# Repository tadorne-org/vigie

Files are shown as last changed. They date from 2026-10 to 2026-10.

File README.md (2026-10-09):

# Vigie

**La vigie de la batterie.** Un nœud d'énergie toujours vivant pour petits
voiliers : une carte qui mesure l'énergie à bord, veille à quelques
microampères et rend compte depuis la cale — toute l'année, coupe-circuit
ouvert. Un projet [Tadorne](https://tadorne.org/).

## Le problème

Une batterie se vide pendant que le bateau est laissé seul. Les causes
habituelles — un instrument resté câblé en direct, un convertisseur qui ne
dort jamais, aucune recharge — sont invisibles depuis le quai.

## L'approche

- **Un seul nœud reste vivant.** Alimenté en amont du coupe-circuit, il mesure
  toute l'installation et rend compte ; tout le reste du bord peut être éteint
  ou en panne.
- **Un seul point de vérité.** Tout le courant passe par un shunt unique, lu
  en quatre fils dans le bus négatif. Aucun courant de charge ne traverse la
  carte.
- **Une veille qui ne vide pas.** Conversion choisie pour son courant de
  repos : ce qu'un convertisseur classique prendrait en un mois, Vigie le
  prend en un an.
- **Un réseau, pas un boîtier.** Vigie est la passerelle d'un petit réseau
  radio : afficheurs, centrale d'attitude, capteur de vent, second capteur de
  courant rejoignent au besoin, et chacun peut tomber sans emporter le reste.

## État

**Vigie 1.0** : carte conçue, assemblée, premiers tests concluants. Le projet
KiCad est publié sous CERN-OHL-S v2 ; le micrologiciel suivra, sous sa propre
licence. Huit jalons, du banc à une saison à flot :
[feuille de route](https://vigie.tadorne.org/fr/feuille-de-route/) ·
[documentation technique](https://vigie.tadorne.org/fr/documentation/) ·
[journal](https://vigie.tadorne.org/fr/journal/).

## Contenu du dépôt

| Dossier | Contenu | Licence |
|---|---|---|
| [`pcb/`](pcb/) | Projet KiCad de Vigie 1.0 : schéma, carte quatre couches, bibliothèque de symboles | [CERN-OHL-S v2](pcb/LICENSE) |
| [`site/`](site/) | Source Hugo de [vigie.tadorne.org](https://vigie.tadorne.org/) | contenu [CC BY-SA 4.0](site/LICENSE-CONTENT), gabarits [MIT](site/LICENSE) |

Le contenu de `pcb/` (tag `v1.0`) est identique à l'archive publiée, signée et
horodatée :
[`vigie-1.0-kicad.zip`](https://vigie.tadorne.org/files/vigie-1.0/vigie-1.0-kicad.zip),
[signature](https://vigie.tadorne.org/files/vigie-1.0/vigie-1.0-kicad.zip.asc),
[horodatage FreeTSA](https://vigie.tadorne.org/files/vigie-1.0/vigie-1.0-kicad.zip.tsr).

## Authenticité

Les commits et les fichiers publiés sont signés par la clé Tadorne
(`5420 08E3 53EC A628 B4D6  ACAD 8C03 243A FF69 5BF7`) ; chaque commit est
horodaté par FreeTSA (RFC 3161), jeton rangé dans les notes Git
`refs/notes/freetsa`. Vérification : <https://tadorne.org/verify/>.

```sh
git fetch origin refs/notes/freetsa:refs/notes/freetsa
git notes --ref freetsa show HEAD
```

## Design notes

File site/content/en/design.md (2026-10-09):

---
title: "The design"
translationKey: design
url: /design/
description: "Schematic, placement and routing, regenerated by versioned scripts."
---

Vigie is not drawn by hand. Its schematic, footprint placement and routing are produced by scripts kept with the design, so the same command rebuilds the same files.

- The schematic comes from a single description of the components and the nets.
- Board outline, mounting holes, footprint placement and the internal ground and 3.3 V planes are scripted.
- Signal routing is delegated to a router on the two outer layers only; the inner layers stay solid planes.
- Every build ends with a netlist check pin by pin, an electrical rule check and a design rule check.

{{< callout title="Board" >}}
86 × 54 mm, four layers, sixty-nine footprints, fifty-four nets. Measurement across an external 100 A shunt, four-wire.
{{< /callout >}}

The KiCad project is published under [CERN-OHL-S v2](/files/vigie-1.0/LICENSE-CERN-OHL-S-2.0.txt): [archive](/files/vigie-1.0/vigie-1.0-kicad.zip), its [signature](/files/vigie-1.0/vigie-1.0-kicad.zip.asc) and [FreeTSA timestamp](/files/vigie-1.0/vigie-1.0-kicad.zip.tsr). The bill of materials exports from the schematic; the calibration procedure will follow with the firmware.

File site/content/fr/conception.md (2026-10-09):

---
title: "La conception"
translationKey: design
url: /fr/conception/
description: "Schéma, implantation et routage, régénérés par des scripts versionnés."
---

Vigie n'est pas dessinée à la main. Son schéma, l'implantation des empreintes et le routage sont produits par des scripts conservés avec la conception : la même commande reconstruit les mêmes fichiers.

- Le schéma provient d'une description unique des composants et des nets.
- Contour de carte, trous de fixation, implantation des empreintes et plans internes de masse et de 3,3 V sont scriptés.
- Le routage des signaux est confié à un routeur, sur les deux couches externes seulement ; les couches internes restent des plans pleins.
- Chaque build se termine par un contrôle de la netlist broche par broche, un contrôle des règles électriques et un contrôle des règles de dessin.

{{< callout title="Carte" >}}
86 × 54 mm, quatre couches, soixante-neuf empreintes, cinquante-quatre nets. Mesure aux bornes d'un shunt externe de 100 A, en quatre fils.
{{< /callout >}}

Le projet KiCad est publié sous [CERN-OHL-S v2](/files/vigie-1.0/LICENSE-CERN-OHL-S-2.0.txt) : [archive](/files/vigie-1.0/vigie-1.0-kicad.zip), sa [signature](/files/vigie-1.0/vigie-1.0-kicad.zip.asc) et son [horodatage FreeTSA](/files/vigie-1.0/vigie-1.0-kicad.zip.tsr). La nomenclature s'exporte du schéma ; la procédure d'étalonnage suivra avec le micrologiciel.

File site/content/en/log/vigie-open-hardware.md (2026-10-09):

---
title: "Vigie goes open hardware"
translationKey: log/vigie-open-hardware
date: 2026-09-28
description: "Vigie 1.0's schematic and four-layer board are published under CERN-OHL-S v2."
params:
  tags: ["vigie", "hardware", "licence"]
---

Vigie 1.0's KiCad project is published under the **CERN-OHL-S v2** hardware
licence. Schematic, four-layer board and symbol library: the minimum needed to
open, study and rebuild the board is downloadable now.

## What is published

| Item | Format |
|---|---|
| Schematic | KiCad |
| Printed circuit board | KiCad, four layers, routed |
| Library | the project's `CH340C_3V3` symbol |

The project opens as-is in KiCad 10. The bill of materials is not supplied
separately: it exports straight from the schematic, with KiCad's own tools.

## Responsibility and limits

- **The board is untested.** Integration testing is under way, and the real
  quiescent current is not measured yet. The design is published as it stands,
  open points included — antenna in a closed locker, shunt orientation to be
  confirmed.
- **No warranty.** The licence text is explicit: the source is provided as-is.
  A board switching 12 V aboard involves the safety of whoever wires it.
- **Firmware is still to be published.** This archive covers the hardware; the
  code that reads the INA226 and keeps watch through the winter will follow
  under its own licence.

## Where

- [KiCad project (ZIP)](/files/vigie-1.0/vigie-1.0-kicad.zip)
- [Detached signature (`.asc`)](/files/vigie-1.0/vigie-1.0-kicad.zip.asc)
- [FreeTSA timestamp (`.tsr`)](/files/vigie-1.0/vigie-1.0-kicad.zip.tsr)
- [CERN-OHL-S v2 licence text](/files/vigie-1.0/LICENSE-CERN-OHL-S-2.0.txt)

The archive is signed with the Tadorne publication key; the fingerprint is in
the page footer. It is also timestamped by FreeTSA (RFC 3161).

The published source is authoritative; it is also described on [the Design
page](/design/), which recalls how the board is produced.

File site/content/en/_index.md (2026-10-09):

---
title: "Vigie"
translationKey: home
description: "An always-on energy node for small boats: one board that measures the battery, watches through the winter and reports from the bilge. A Tadorne project."
params:
  hero:
    eyebrow: "A Tadorne project"
    lead: "The battery's lookout. One board that measures the energy aboard, keeps watch on a few microamps and reports from the bilge — all year, main switch off."
    ctas:
      - label: "The project"
        url: "/project/"
      - label: "The design"
        url: "/design/"
      - label: "Kit — coming soon"
        url: "/interest/"
        solid: true
  video:
    mp4: "/video/vigie-en.mp4"
    webm: "/video/vigie-en.webm"
    poster: "/video/vigie-en-poster.jpg"
    caption: "Vigie 1.0: the exploded stack, then the board aboard — shunt, Kelvin pair, Bluetooth LE."
  figures:
    - label: "Board"
      value: "86 × 54 mm"
    - label: "Layers"
      value: "4"
    - label: "Watch current"
      value: "22 µA"
    - label: "Measured current"
      value: "100 A"
    - label: "Regime"
      value: "All year"
  notes:
    - title: "One point of truth"
      body: "All current passes the shunt; the board only reads it. No second path, no silent error."
    - title: "Always alive"
      body: "Fed upstream of the main switch, it is the one module that outlives the winter."
    - title: "Built from scripts"
      body: "Schematic, placement and routing are regenerated by versioned code, not drawn by hand."
  closing:
    title: "Join Vigie"
    body: "Beta testers and contributors wanted. The board is on the bench, the season afloat comes next."
    url: "mailto:contact@tadorne.org?subject=Vigie%20%E2%80%94%20beta%20testing%20%2F%20contribution&body=Hello%2C%0A%0AI%20would%20like%20to%20get%20involved%20in%20Vigie.%0A%0AWhat%20I%20can%20bring%3A%0A-%0A%0AWhat%20I%20am%20looking%20for%3A%0A-%0A%0AThanks."
    label: "Write to us"
---

Battery state read at the shunt, and a watch kept all year.

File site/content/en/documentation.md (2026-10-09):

---
title: "Technical documentation"
translationKey: documentation
url: /documentation/
description: "Architecture, board, measurement, firmware and network of Vigie 1.0 — work in progress."
params:
  eyebrow: "Vigie 1.0"
---

{{< callout title="Work in progress" >}}
This page is the documentation of **Vigie 1.0**, still being written.

**[See the log](/log/)** for the latest state.
{{< /callout >}}

Vigie is a single board that measures the energy of a sailboat or a 12 V battery
pack, keeps watch all year and reports. It replaces the "ESP32 devkit + INA226
module + LM2596 converter" stack with an 86 × 54 mm four-layer board, and sits
**upstream of the main switch** — the one module that stays alive through the
winter: its converters draw 22 µA per stage, and the whole board stays below a
milliamp.

<figure class="doc">
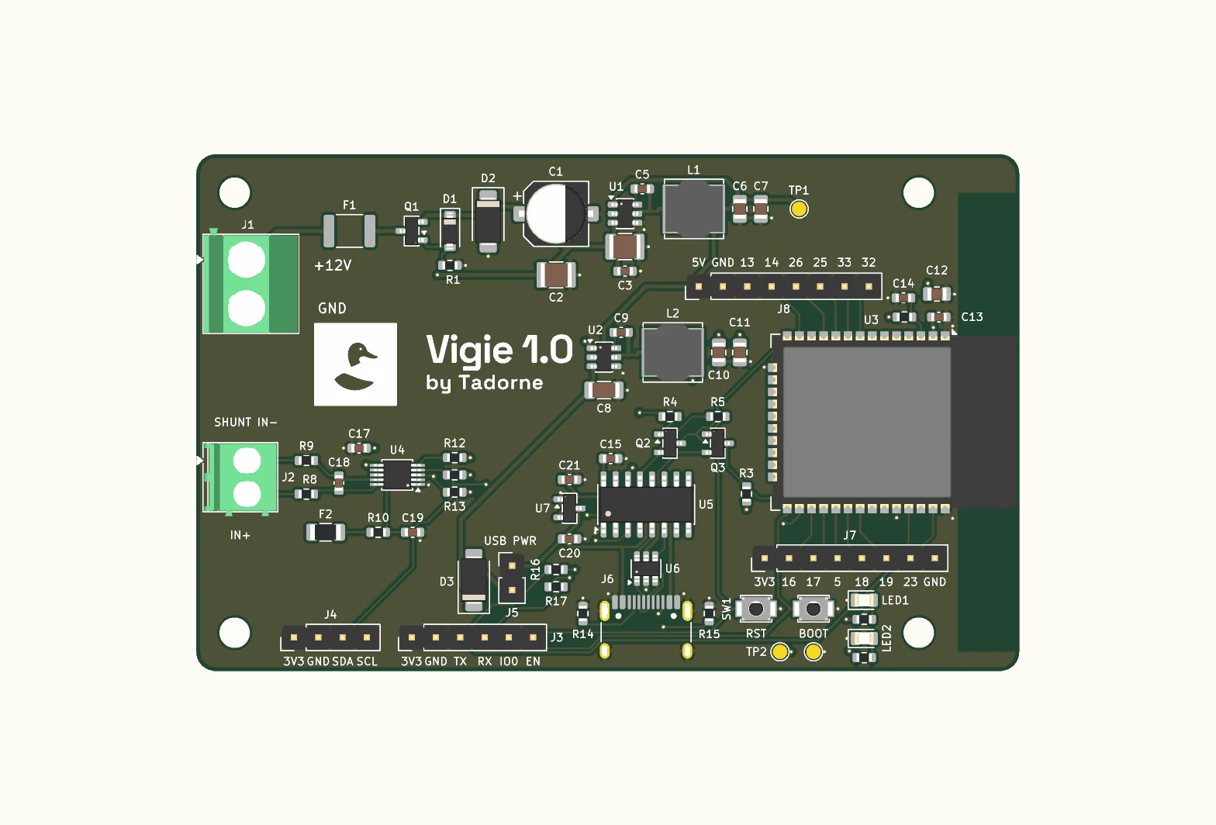
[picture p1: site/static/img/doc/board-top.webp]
Render of the Vigie 1.0 board, component side.
  
  <figcaption><b>Vigie 1.0</b>, component side: 12 V and shunt terminals on the left, ESP32-WROOM-32E on the right, converters in the middle, "Vigie 1.0 — by Tadorne" in the silkscreen.</figcaption>
</figure>

## Overview

One point of truth: all current aboard flows through a **100 A / 75 mV shunt**
in the negative bus, and the board only reads the voltage across it, in four
wires. No load current flows through the board.

<figure class="doc">
  Block diagram of Vigie 1.0: power, measurement, programming and expansion around the ESP32.
  <figcaption>Block diagram: 12 V → 5 V → 3.3 V power chain, Kelvin-wired INA226 measurement, USB-C programming and expansion headers, around the ESP32-WROOM-32E.</figcaption>
</figure>

| Characteristic | Value |
|---|---|
| Dimensions | 86 × 54 mm, R2 corners, four M3 holes |
| Layers | 4: signal / ground plane / +3.3 V plane / signal |
| Microcontroller | ESP32-WROOM-32E, PCB antenna on the right flank, copper-free zone on all four layers |
| Measurement | INA226AIDGSR, external 100 A / 75 mV shunt, four-wire Kelvin connection |
| Power | 12 V → 5 V → 3.3 V, 2 A per stage, 22 µA quiescent current per stage |
| Protection | polyfuse, reverse-polarity P-MOSFET, SMAJ16A TVS, 100 mA fuse on VBUS |
| Programming | CH340C + USB-C, automatic DTR/RTS reset |
| Expansion | two 1×8 headers: 12 GPIO, +3.3 V, +5 V, I2C, UART, reserved RS485 |
| Footprints | 69 footprints and 4 holes, 54 nets |

## The board

### Power

Two switching converters from the same family share the chain: **AP63205WU** for
12 V → 5 V and **AP63203WU** for 5 V → 3.3 V, 2 A each at 1.1 MHz. The hard
point of an always-on node is their quiescent current: **22 µA per stage**, where
an LM2596 draws 5 to 10 mA continuously, about 3.5 Ah a month taken for nothing.

The input is protected by a polyfuse, a reverse-polarity P-MOSFET (45 mΩ, with
its gate zener — mandatory, since the battery reaches 14.4 V while charging) and
an SMAJ16A TVS. On the bench, jumper **J5** powers the board from USB; it is open
by default so the 5 V cannot climb back to the battery terminal. The **CH340C**
is powered by an LDO taken from USB VBUS alone: unplugged, it draws nothing.

### Measurement

The INA226 works across a **0.75 mΩ** shunt in the negative bus: 75 mV of common
mode instead of 12 V, and `VBUS` reads the battery voltage directly. Its range is
fixed at **±81.92 mV** — the `ADCRANGE` bit does not exist on this part, unlike
the INA228 — which gives, with the native 2.5 µV step, a resolution of
**3.33 mA**. One hundred amps use 91.6 % of full scale.

Gain, zero and current sign are set in software (`i_gain`, `i_offset_mA`,
`i_invert`): a J2 wired the wrong way round is corrected without taking the
board apart. Amp-hour counting is software too, since the INA226 has no charge
accumulator. Finally, `ALERT` arrives on **GPIO 4**, an RTC pin: it can wake the
ESP32 from deep sleep.

<figure class="doc">
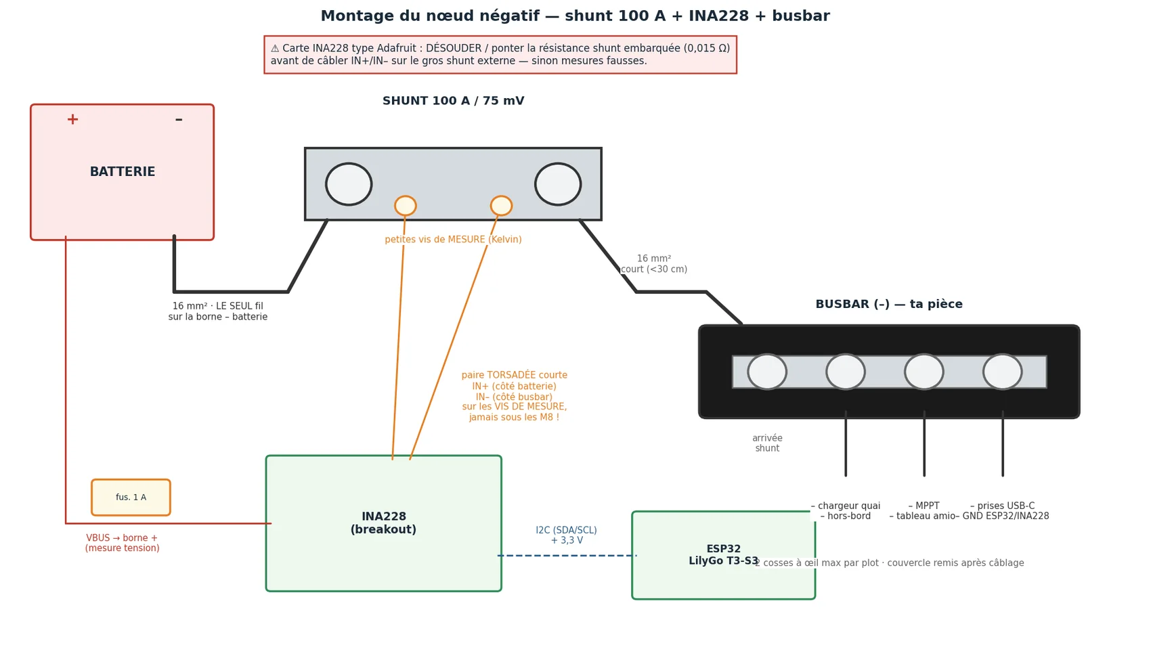
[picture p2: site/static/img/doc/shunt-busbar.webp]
Mounting the node on the negative bus: shunt, Kelvin pair and busbar.
  
  <figcaption>The negative-bus mounting, study figure: the Kelvin pair is taken
  from the shunt's <b>small measurement screws</b>, never from under the power
  bolts, and the board's return joins the negative bus as close to the shunt as
  possible. The principle is Vigie 1.0's own, which carries no load
  current.</figcaption>
</figure>

The precaution is not theoretical: at 100 A, 20 cm of 16 mm² cable is already
23 mV, close to a third of the measurement range.

### Routing and placement

The two inner layers are **solid planes with no tracks at all**: In1 for ground,
In2 for +3.3 V. Every SMD ground and +3.3 V pad drops to its plane through its
own via, placed and locked before routing. Signal routing fits on the two outer
layers.

<figure class="doc">
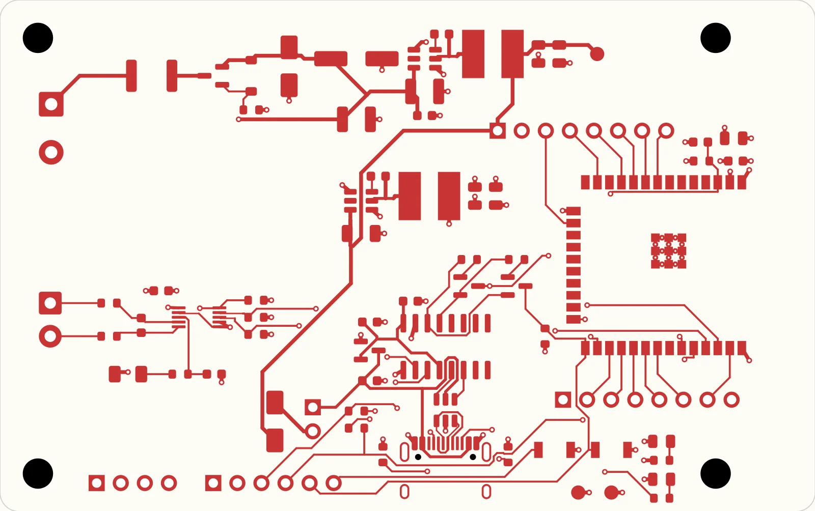
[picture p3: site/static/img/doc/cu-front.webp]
Front copper routing of Vigie 1.0.
  
  <figcaption>Front copper routing (F.Cu): signals fit on the two outer layers,
  the two inner layers staying solid planes.</figcaption>
</figure>

<figure class="doc">
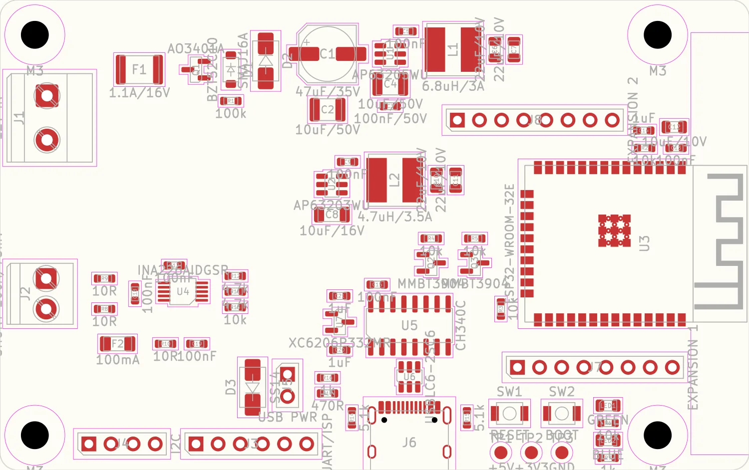
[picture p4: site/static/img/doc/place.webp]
Placement and silkscreen of Vigie 1.0.
  
  <figcaption>Placement and silkscreen: every reference is placed where it covers
  neither a pad nor a via.</figcaption>
</figure>

### Connectors

| Ref. | Role | Pinout |
|---|---|---|
| J1 | 12 V input (5.08 mm terminal block) | 1 = +12 V battery (external 2 A fuse) · 2 = GND, load side of the negative bus |
| J2 | Shunt (3.5 mm terminal block) | 1 = IN− · 2 = IN+ — sign to be confirmed at bring-up |
| J3 | UART / ISP | 3V3 · GND · TX · RX · IO0 · EN |
| J4 | I2C | 3V3 · GND · SDA · SCL |
| J5 | USB PWR jumper | close to power from USB, without the battery only |
| J6 | USB-C | programming |
| J7 | Expansion 1 | 3V3 · IO16 · IO17 · IO5 · IO18 · IO19 · IO23 · GND |
| J8 | Expansion 2 | 5V · GND · IO13 · IO14 · IO26 · IO25 · IO33 · IO32 |

I2C is on SDA 21 / SCL 22, the status LED on GPIO 2, the BOOT button on GPIO 0,
the console on TX 1 / RX 3. GPIO 16, 17 and 18 are grouped on J7 for the MPPT's
future RS485. The strapping pins 12 and 15, like GPIO 34 to 39, are not brought
out.

## Firmware

The firmware runs on PlatformIO, with a pinned pioarduino platform
(Arduino-ESP32 3.3.11 / ESP-IDF 5.5) and no external library. It already runs on
a bare ESP32 devkit: a battery simulator stands in for the missing INA226, and
every simulated measurement carries the `SIM` flag all the way into the log and
onto the air.

The cycle is deep sleep broken by short wake-ups:

| Task | Default period | Cost |
|---|---|---|
| Measurement | 5 min | 110 ms awake |
| Recording | 5 min | average, minimum and maximum of the period |
| Brief BLE advertisement | at every measurement | about 0.4 s awake, estimated |
| Radio push | 15 min | 1.8 s awake, of which 1.1 s of BLE advertising |
| Wintering | push every 6 h | survival mode |

Measurement averages 1024 INA226 conversions, a **9.6 s** sliding window that
keeps averaging while the ESP32 sleeps. State of charge is coulometric counting:
trapezoids between measurements, 0.90 charge efficiency, Peukert exponent 1.25
in discharge beyond C/20. It resynchronises to 100 % when the voltage holds
above the threshold with a low tail current, and re-anchors on the open-circuit
voltage table after four hours at rest.

The log lives in a raw 896 KB partition, with no file system: 32-byte records
protected by a CRC. At the default cadence the ring keeps about **95 days** of
samples and **2.5 years** of daily summaries. The board has no backed-up clock:
time arrives from the admin page, from the gateway or from the console, and a
`time_sync` record makes it possible to date what came before.

Battery protection is a staircase, and a degradation needs two consecutive
evaluations — an engine start does not cut the node:

| Voltage | State | Effect |
|---|---|---|
| 12.2 V and above | nominal | |
| below 12.2 V | throttled | push halved |
| below 11.9 V | survival | push every 6 h, no catch-up |
| below 11.5 V | cutoff | final alert, then radio silence; the INA226 wakes the node once the voltage is back above 12.6 V |

Administration is an access point, `Vigie-XXXX` (WPA2, captive portal), opened
on cold start or by holding BOOT: dashboard, 6 h to 30 day history with CSV
exports, settings, SOC reset, OTA update and log erase. The serial console
offers the same functions.

<figure class="doc">
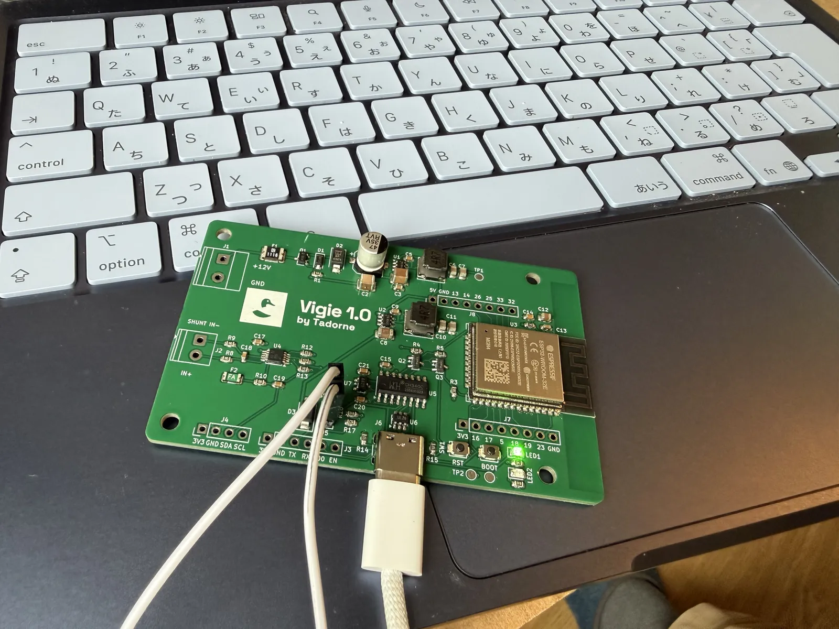
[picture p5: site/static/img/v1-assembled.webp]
Assembled Vigie 1.0 board, powered over USB-C, on the bench.
  
  <figcaption>The first assembled board: 3.3 V present, CH340C recognised, firmware running, INA226 answering on I2C.</figcaption>
</figure>

<figure class="doc">
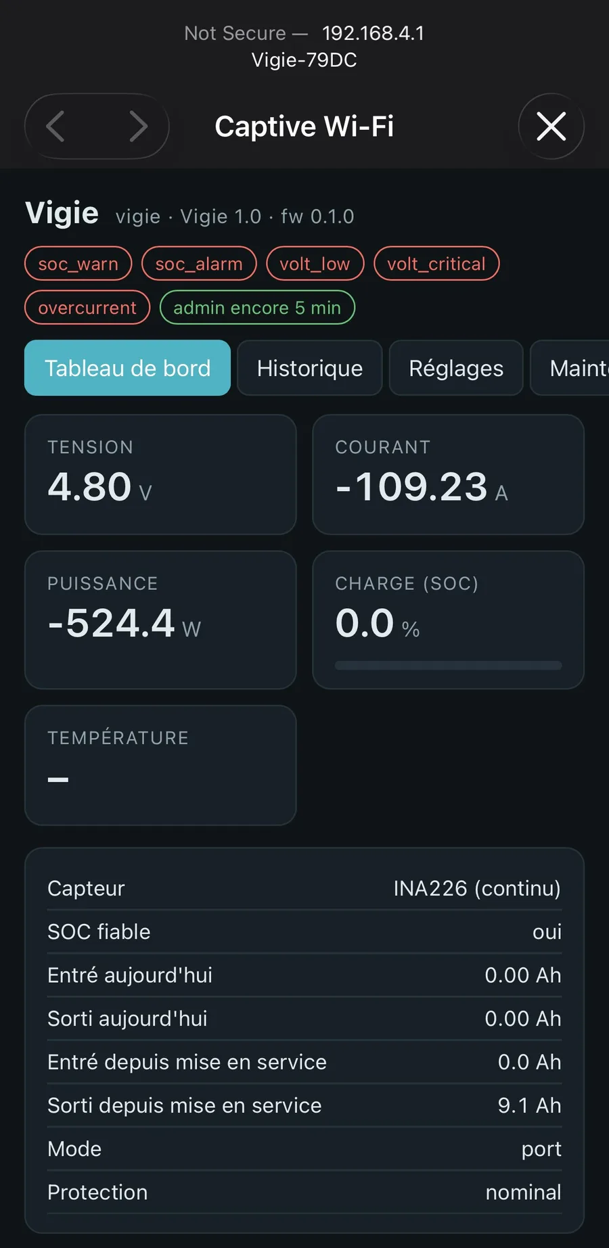
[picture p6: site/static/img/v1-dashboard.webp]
Vigie 1.0 dashboard, served from the board's own access point.
  
  <figcaption>The admin page, served from the board's own access point. With no shunt, the current columns still show the INA226's full scale.</figcaption>
</figure>

## Network and application

The node pushes its measurements in two complementary ways. On the local
network, **TsubameBus**: encrypted ESP-NOW frames, a 12-byte header and a CBOR
body, with `HELLO`, `ENERGY`, `ALERT` and `LOG_BATCH`. A receiver acknowledges
the last record it got, so a module absent for a week recovers the whole week
when it returns. Towards phones, a **[BTHome v2](https://bthome.io)**
advertisement over Bluetooth LE, readable as-is by Home Assistant or nRF
Connect, with optional AES-CCM encryption.

A [Signal K](https://signalk.org/) implementation is planned.

| What Vigie broadcasts | Received by an iPhone | Content |
|---|---|---|
| BLE BTHome v2 advertisement | yes | state of charge, voltage, current, power, temperature |
| Scan response (manufacturer block) | yes | Bluetooth MAC, status flags, active alerts |
| ESP-NOW frames | no | iOS gives no access to raw Wi-Fi frames |

The **Tadorne** iPhone app listens passively: no connection, no pairing, nothing
is transmitted. It keeps the history of what it caught, with the app open; the
full log stays in the node's flash.

<div class="photo-grid">
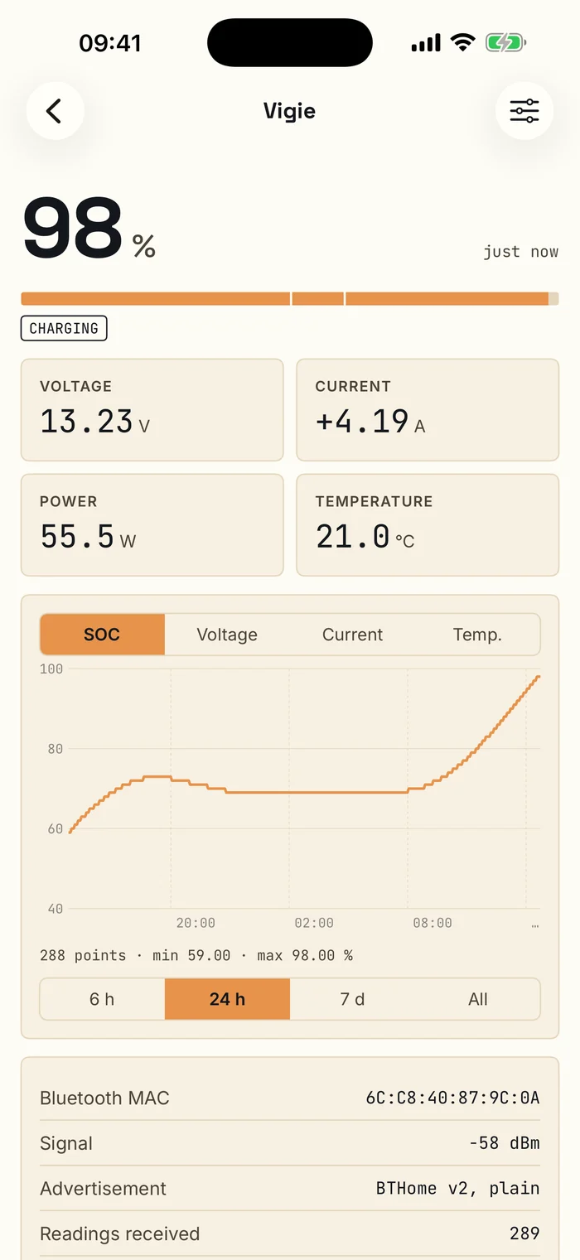
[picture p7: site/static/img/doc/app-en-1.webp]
Node detail screen in the Tadorne app: state of charge, measurements and chart.
  
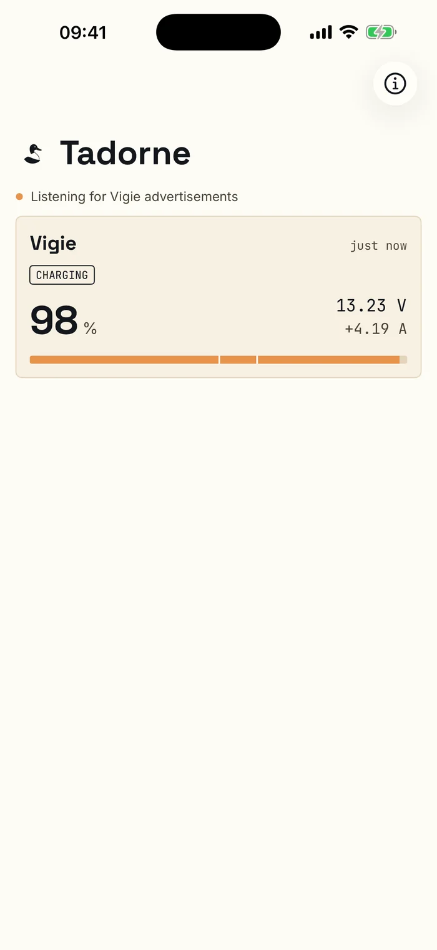
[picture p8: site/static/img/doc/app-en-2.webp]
Node list in the Tadorne app.
  
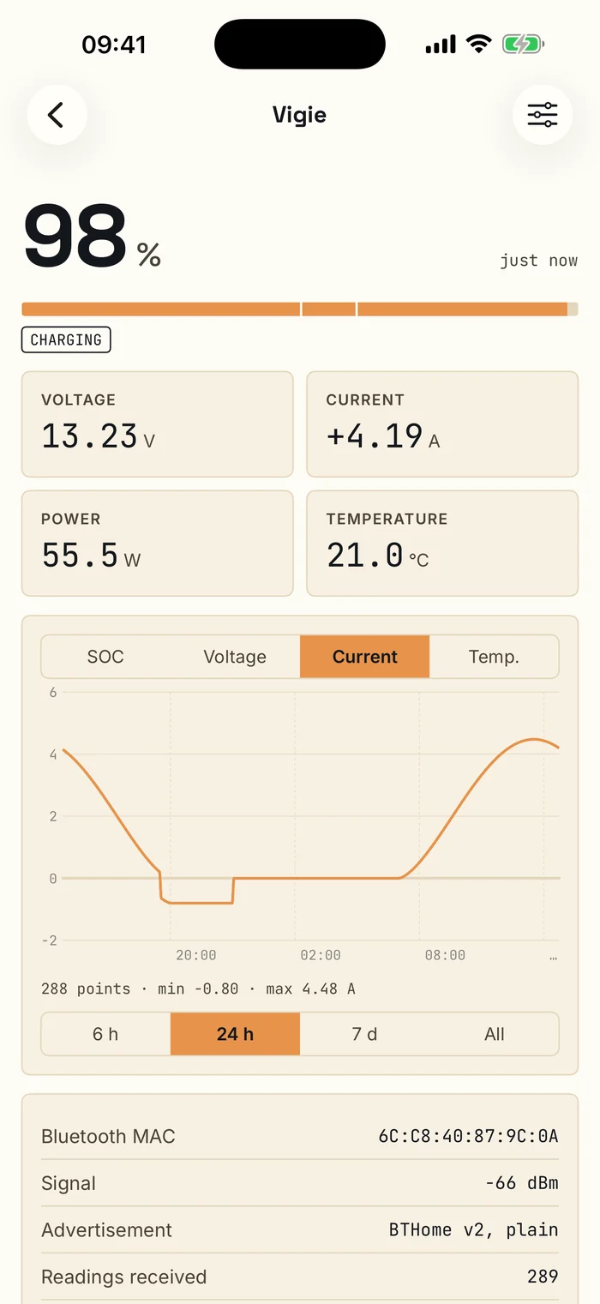
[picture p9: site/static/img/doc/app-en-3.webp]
Current history in the Tadorne app.
  
</div>

<p class="meta">Tadorne app — node detail, node list, current history.</p>

This revision of the board carries **neither LoRa nor LTE**: it is the
measurement post, not the Internet gateway. The radio arbitration remains open,
and the gateway will join the network without modifying the board.

## State and open points

| Point | State |
|---|---|
| Real quiescent current | to be measured at bring-up — it is what sets the winter autonomy |
| Current sign at the shunt | to be confirmed at first wiring |
| Antenna in a closed locker, in the bilge | open point; the ESP32-WROOM-32UE variant, with a u.FL remote antenna, fits the same footprint |
| RS485 for the EPEver MPPT | not fitted; external MAX3485 module on J7 |
| Firmware | still to be published |
| Bill of materials and calibration procedure | to come with the firmware |

The bench validated the build of all three environments, the sleep cycle, the
log and its recovery after reset, the 100 % resynchronisation and the low-voltage
cutoff. Real ESP-NOW frame reception, BLE reception and everything touching the
real INA226 remain to be verified on the board.

## Source: the log

Every note in the log is a source for this page, and the log is authoritative.

{{< log-sources >}}

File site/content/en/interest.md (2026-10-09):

---
title: "Registering interest"
translationKey: interest
url: /interest/
eyebrow: "Vigie 1.0 — pre-series"
description: "Neither a sale nor a pre-order: a list of interested people, to decide whether a small batch makes sense."
figures:
  - label: "Board"
    value: "86 × 54 mm"
  - label: "Measurement"
    value: "INA226 · 100 A shunt"
  - label: "Sleep current"
    value: "22 µA"
  - label: "Status"
    value: "On the bench"
---

**Vigie** is the energy node board: an ESP32 and an INA226 that measure a small sailboat's battery, upstream of the main switch, down to a few microamps — enough to last a whole winter layup without draining the battery.

Vigie 1.0 is arriving on the bench. A few boards will be assembled beyond what the boat needs. Before turning it into a product — and before taking on the conformity work that selling imposes — one question remains: **does this object interest anyone other than its author?**

This page exists to answer that. It sells nothing.

{{< callout title="What this page is not" >}}
- It is **not a pre-order**: no payment, no commitment, no promised date.
- It is **not a reservation**: the number of boards available is not known yet.
- It is **not a form**: the message is sent from the visitor's own mail client. No script, no cookie, no data passed to a third party — as everywhere on this site.
{{< /callout >}}

## Answering

The link below opens a pre-filled message. Six lines are enough. The message goes straight from your mail client to `contact@tadorne.org`; nothing passes through the site.

<p style="margin-top:1.5rem"><a class="btn btn--solid" href="mailto:contact@tadorne.org?subject=Vigie%201.0%3A%20registering%20interest&amp;body=Boat%20%28model%2C%20length%29%3A%0D%0AHome%20port%20and%20sailing%20area%3A%0D%0ACurrent%20installation%20%28battery%2C%20charging%2C%20shunt%20if%20any%29%3A%0D%0AWhat%20would%20interest%20you%20%28board%20only%20%2F%20kit%3A%20board%20%2B%20shunt%20%2B%20spacers%20%2F%20follow%20the%20project%29%3A%0D%0AWintering%20aboard%3A%20yes%20%2F%20no%0D%0APreferred%20documentation%20language%3A%20English%20%2F%20French">Write to Tadorne</a></p>

If the link does not open, write to `contact@tadorne.org` with these six lines:

1. Boat — model, length
2. Home port and sailing area
3. Current installation — battery, charge, shunt if any
4. What would interest you — board only, kit (board + shunt + spacers), or simply following the project
5. Wintering aboard — yes or no
6. Preferred documentation language — English or French

## What happens next

Every message gets an answer. People on this list are told first if a small batch goes ahead, and before any public announcement.

Replies are used only to decide what the project does next. They are neither sold nor shared, and a single message is enough to have them deleted.

Progress is kept up to date in [the roadmap](/roadmap/) and [the log](/log/).

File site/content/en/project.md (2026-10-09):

---
title: "The project"
translationKey: project
url: /project/
description: "One board that measures the boat's energy, all year round."
params:
  eyebrow: "Vigie"
---

## The problem

A battery goes flat while the boat is left alone. The usual causes — an instrument still wired live, a converter that never sleeps, no recharge at all — are invisible from the quay.

## The approach

One node, fed upstream of the main switch, is the only thing that stays alive: it measures the whole installation and reports. Everything else on board may be switched off or broken; the watch goes on.

## One point of truth

All current passes through a single shunt, in the negative bus. The board reads the voltage across it in four wires — two for the load, two for the measure. No charge flows through the board itself, so nothing sits in parallel to falsify the count.

## The quiet drain

A watch is only useful if it does not itself empty the battery. Conversion is chosen for its quiescent current, counted in microamps rather than milliamps: what a conventional converter would take in a month, Vigie takes in a year.

## A network, not a box

Vigie is the always-on gateway of a small radio network. Displays, an attitude sensor, a wind sensor, a second current sensor: each joins when needed, and each may fail without taking the rest down.

## The horizon

The design — schematic, placement, routing — is produced by versioned scripts and published as a commons. The next steps are a second current sensor for the outboard, an attitude node and a wind sensor at the masthead.

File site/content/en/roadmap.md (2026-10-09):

---
title: "Roadmap"
translationKey: roadmap
url: /roadmap/
type: roadmap
description: "Eight milestones, from the bench to a season afloat."
params:
  milestones:
    - id: "M1"
      title: "Bench validated"
      body: "The measurement chain calibrated against a reference; the real quiescent current measured."
    - id: "M2"
      title: "First boards"
      body: "Four-layer boards fabricated, assembled and brought up."
    - id: "M3"
      title: "Firmware v1"
      body: "Measurement, state of charge, remote reporting, watchdog."
    - id: "M4"
      title: "Afloat"
      body: "Node installed upstream of the main switch; a full season with the boat."
    - id: "M5"
      title: "Through the winter"
      body: "Telemetry kept through layup; the consumption budget held."
    - id: "M6"
      title: "Open design"
      body: "Schematic, scripts, bill of materials and calibration published."
    - id: "M7"
      title: "Second sensor"
      body: "Outboard charging current on the same bus, no extra cable."
    - id: "M8"
      title: "Beyond energy"
      body: "Attitude and wind nodes join the same network."
---

The board is fixed first. Everything else joins it.

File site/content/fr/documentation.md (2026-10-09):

---
title: "Documentation technique"
translationKey: documentation
url: /fr/documentation/
description: "Architecture, carte, mesure, micrologiciel et réseau de Vigie 1.0 — travail en cours."
params:
  eyebrow: "Vigie 1.0"
---

{{< callout title="Travail en cours" >}}
Cette page est la documentation de **Vigie 1.0**, encore en cours d'élaboration.

**[Voir le journal](/fr/journal/)** pour l'état le plus récent.
{{< /callout >}}

Vigie est une carte unique qui mesure l'énergie d'un voilier ou d'un pack
batterie 12 V, veille toute l'année et rend compte. Elle remplace l'empilage
« devkit ESP32 + module INA226 + convertisseur LM2596 » par une carte de
86 × 54 mm à quatre couches, et se place **en amont du coupe-circuit** — le seul
module qui reste vivant l'hiver : ses convertisseurs se contentent de 22 µA par
étage, et l'ensemble reste sous le milliampère.

<figure class="doc">
  Rendu de la carte Vigie 1.0 côté composants.
  <figcaption><b>Vigie 1.0</b>, côté composants : borniers 12 V et shunt à gauche, ESP32-WROOM-32E à droite, convertisseurs au centre, logo « Vigie 1.0 — by Tadorne » en sérigraphie.</figcaption>
</figure>

## Vue d'ensemble

Un seul point de vérité : tout le courant du bord passe par un **shunt de
100 A / 75 mV** monté dans le bus négatif, et la carte ne fait que lire la
tension à ses bornes, en quatre fils. Aucun courant de charge ne la traverse.

<figure class="doc">
  Schéma-bloc de Vigie 1.0 : alimentation, mesure, programmation et extensions autour de l'ESP32.
  <figcaption>Schéma-bloc de la carte : chaîne d'alimentation 12 V → 5 V → 3,3 V, mesure INA226 en Kelvin, programmation USB-C et extensions, autour de l'ESP32-WROOM-32E.</figcaption>
</figure>

| Caractéristique | Valeur |
|---|---|
| Dimensions | 86 × 54 mm, coins R2, quatre trous M3 |
| Couches | 4 : signal / plan de masse / plan +3,3 V / signal |
| Microcontrôleur | ESP32-WROOM-32E, antenne PCB au flanc droit, zone sans cuivre sur les quatre couches |
| Mesure | INA226AIDGSR, shunt externe 100 A / 75 mV, liaison Kelvin quatre fils |
| Alimentation | 12 V → 5 V → 3,3 V, 2 A par étage, courant de repos 22 µA par étage |
| Protections | polyfuse, P-MOSFET anti-inversion, TVS SMAJ16A, fusible 100 mA sur VBUS |
| Programmation | CH340C + USB-C, réinitialisation automatique DTR/RTS |
| Extension | deux barrettes 1×8 : 12 GPIO, +3,3 V, +5 V, I2C, UART, RS485 réservé |
| Empreintes | 69 empreintes et 4 trous, 54 nets |

## La carte

### L'alimentation

Deux convertisseurs à découpage de la même famille se partagent la chaîne :
**AP63205WU** pour le 12 V → 5 V et **AP63203WU** pour le 5 V → 3,3 V, 2 A
chacun à 1,1 MHz. Le point dur d'un nœud alimenté toute l'année est leur
courant de repos : **22 µA par étage**, là où un LM2596 en consomme 5 à 10 mA
en permanence, soit environ 3,5 Ah par mois prélevés pour rien.

L'entrée est protégée par une polyfuse, un P-MOSFET anti-inversion (45 mΩ, avec
sa zener de grille — obligatoire, la batterie monte à 14,4 V en charge) et une
TVS SMAJ16A. Sur la paillasse, le cavalier **J5** alimente la carte par l'USB ;
il est ouvert par défaut pour que le 5 V ne remonte pas jusqu'au bornier
batterie. Le **CH340C** est alimenté par un LDO pris sur le VBUS de l'USB seul :
débranché, il ne consomme rien.

### La mesure

L'INA226 travaille sur un shunt de **0,75 mΩ** placé dans le bus négatif :
75 mV de mode commun au lieu de 12 V, et `VBUS` lit directement la tension
batterie. Sa plage est figée à **±81,92 mV** — le bit `ADCRANGE` n'existe pas
sur ce composant, contrairement à l'INA228 — ce qui donne, avec le pas natif de
2,5 µV, une résolution de **3,33 mA**. Cent ampères occupent 91,6 % de
l'échelle.

Le gain, le zéro et le signe du courant se règlent en logiciel (`i_gain`,
`i_offset_mA`, `i_invert`) : un J2 câblé à l'envers se corrige sans redémonter
la carte. Le comptage d'ampères-heures est logiciel lui aussi, l'INA226 n'ayant
pas d'accumulateur de charge. Enfin, `ALERT` arrive sur **GPIO 4**, une broche
RTC : elle peut réveiller l'ESP32 d'un sommeil profond.

<figure class="doc">
  Montage du nœud au bus négatif : shunt, paire Kelvin et busbar.
  <figcaption>Le montage au bus négatif, figure d'étude : la paire Kelvin se
  prend sur les <b>petites vis de mesure</b> du shunt, jamais sous les boulons de
  puissance, et le retour de la carte rejoint le bus négatif au plus près du
  shunt. Le principe est celui de Vigie 1.0, qui ne transporte aucun courant de
  charge.</figcaption>
</figure>

La précaution n'est pas théorique : à 100 A, 20 cm de câble 16 mm² valent déjà
23 mV, soit près d'un tiers de l'échelle de mesure.

### Le routage et l'implantation

Les deux couches internes sont des **plans pleins, sans aucune piste** : In1
pour la masse, In2 pour le +3,3 V. Chaque pastille CMS de masse et de +3,3 V
descend au plan par son propre via, posé et verrouillé avant le routage. Le
routage des signaux tient sur les deux couches externes.

<figure class="doc">
  Routage de la couche avant de Vigie 1.0.
  <figcaption>Routage de la couche avant (F.Cu) : les signaux tiennent sur les
  deux couches externes, les deux couches internes restant des plans pleins.</figcaption>
</figure>

<figure class="doc">
  Implantation et sérigraphie de Vigie 1.0.
  <figcaption>Implantation et sérigraphie : chaque repère est placé là où il ne
  recouvre ni pastille ni via.</figcaption>
</figure>

### Connecteurs

| Réf. | Rôle | Brochage |
|---|---|---|
| J1 | Entrée 12 V (bornier 5,08 mm) | 1 = +12 V batterie (fusible 2 A externe) · 2 = GND, côté charge du bus négatif |
| J2 | Shunt (bornier 3,5 mm) | 1 = IN− · 2 = IN+ — sens à valider à la mise en service |
| J3 | UART / ISP | 3V3 · GND · TX · RX · IO0 · EN |
| J4 | I2C | 3V3 · GND · SDA · SCL |
| J5 | Cavalier USB PWR | fermer pour alimenter par l'USB, hors batterie uniquement |
| J6 | USB-C | programmation |
| J7 | Extension 1 | 3V3 · IO16 · IO17 · IO5 · IO18 · IO19 · IO23 · GND |
| J8 | Extension 2 | 5V · GND · IO13 · IO14 · IO26 · IO25 · IO33 · IO32 |

L'I2C est sur SDA 21 / SCL 22, le voyant de statut sur GPIO 2, le bouton BOOT
sur GPIO 0, la console sur TX 1 / RX 3. Les GPIO 16, 17 et 18 sont groupés sur
J7 pour le futur RS485 du MPPT. Les GPIO de strapping 12 et 15, comme les
GPIO 34 à 39, ne sont pas sortis.

## Le micrologiciel

Le micrologiciel tourne sur PlatformIO, plateforme pioarduino figée
(Arduino-ESP32 3.3.11 / ESP-IDF 5.5), sans aucune bibliothèque externe. Il
fonctionne dès maintenant sur une devkit ESP32 nue : un simulateur de batterie
remplace l'INA226 absent, et chaque mesure simulée porte le drapeau `SIM`
jusque dans le journal et sur les ondes.

Le cycle est un sommeil profond entrecoupé de réveils courts :

| Tâche | Période par défaut | Coût |
|---|---|---|
| Mesure | 5 min | 110 ms d'éveil |
| Enregistrement | 5 min | moyenne, minimum et maximum de la période |
| Annonce BLE brève | à chaque mesure | environ 0,4 s d'éveil, estimé |
| Push radio | 15 min | 1,8 s d'éveil, dont 1,1 s d'annonce BLE |
| Hivernage | push toutes les 6 h | mode survie |

La mesure s'appuie sur une moyenne de 1024 conversions de l'INA226, soit une
fenêtre glissante de **9,6 s** qui continue de moyenner pendant que l'ESP32
dort. L'état de charge est un comptage coulométrique : trapèzes entre deux
mesures, rendement de charge 0,90, exposant de Peukert 1,25 en décharge
au-delà de C/20. Il se resynchronise à 100 % quand la tension tient au-dessus
du seuil avec un courant de queue faible, et se recale sur la table de tension
à vide après quatre heures au repos.

Le journal vit dans une partition brute de 896 Ko, sans système de fichiers :
des enregistrements de 32 octets protégés par un CRC. À la cadence par défaut,
l'anneau garde environ **95 jours** d'échantillons et **2,5 ans** de résumés
journaliers. La carte n'a pas d'horloge sauvegardée : l'heure arrive par la
page d'administration, par la passerelle ou par la console, et un
enregistrement `time_sync` permet de dater après coup ce qui précède.

La protection de la batterie est un escalier, et une dégradation exige deux
évaluations consécutives — un démarrage moteur ne coupe pas le nœud :

| Tension | État | Effet |
|---|---|---|
| 12,2 V et plus | nominal | |
| moins de 12,2 V | réduit | push divisé par deux |
| moins de 11,9 V | survie | push toutes les 6 h, sans rattrapage |
| moins de 11,5 V | coupure | alerte finale, puis silence radio ; réveil par l'INA226 dès que la tension repasse au-dessus de 12,6 V |

L'administration se fait par un point d'accès `Vigie-XXXX` (WPA2, portail
captif), ouvert au démarrage à froid ou par appui sur BOOT : tableau de bord,
historique de 6 h à 30 jours avec exports CSV, réglages, recalage du SOC, mise
à jour OTA et effacement du journal. La console série offre les mêmes
fonctions.

<figure class="doc">
  Carte Vigie 1.0 assemblée, alimentée par l'USB-C, sur le banc.
  <figcaption>La première carte assemblée : 3,3 V présent, CH340C reconnu, micrologiciel lancé, INA226 qui répond sur l'I2C.</figcaption>
</figure>

<figure class="doc">
  Tableau de bord de Vigie 1.0 servi depuis le point d'accès de la carte.
  <figcaption>La page d'administration, servie depuis le point d'accès de la carte. Sans shunt, les colonnes de courant affichent encore le fond d'échelle de l'INA226.</figcaption>
</figure>

## Le réseau et l'application

Le nœud pousse ses mesures de deux façons complémentaires. Sur le réseau local,
**TsubameBus** : des trames ESP-NOW chiffrées, en-tête de 12 octets et corps
CBOR, avec `HELLO`, `ENERGY`, `ALERT` et `LOG_BATCH`. Un récepteur accuse
réception du dernier enregistrement reçu, si bien qu'un module absent une
semaine récupère la semaine entière à son retour. Vers les téléphones, une
annonce **[BTHome v2](https://bthome.io)** en Bluetooth LE, lisible telle quelle
par Home Assistant ou nRF Connect, avec chiffrement AES-CCM optionnel.

L'implémentation de [Signal K](https://signalk.org/) est prévue.

| Diffusion de Vigie | Reçue par un iPhone | Contenu |
|---|---|---|
| Annonce BLE BTHome v2 | oui | état de charge, tension, courant, puissance, température |
| Réponse au scan (bloc constructeur) | oui | MAC Bluetooth, drapeaux d'état, alertes actives |
| Trames ESP-NOW | non | iOS ne donne accès à aucune trame Wi-Fi brute |

L'application iPhone **Tadorne** écoute passivement : aucune connexion, aucun
appairage, rien n'est émis. Elle garde l'historique de ce qu'elle a capté, app
ouverte ; le journal complet reste dans la flash du nœud.

<div class="photo-grid">
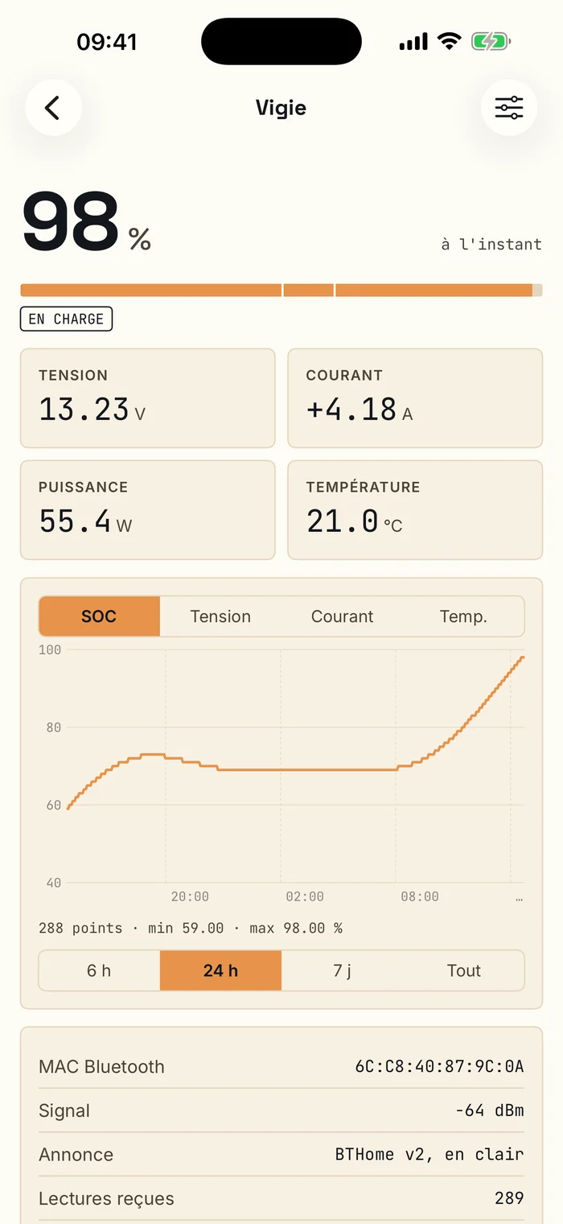
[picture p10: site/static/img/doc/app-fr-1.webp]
Fiche d'un nœud dans l'application Tadorne : état de charge, mesures et graphique.
  
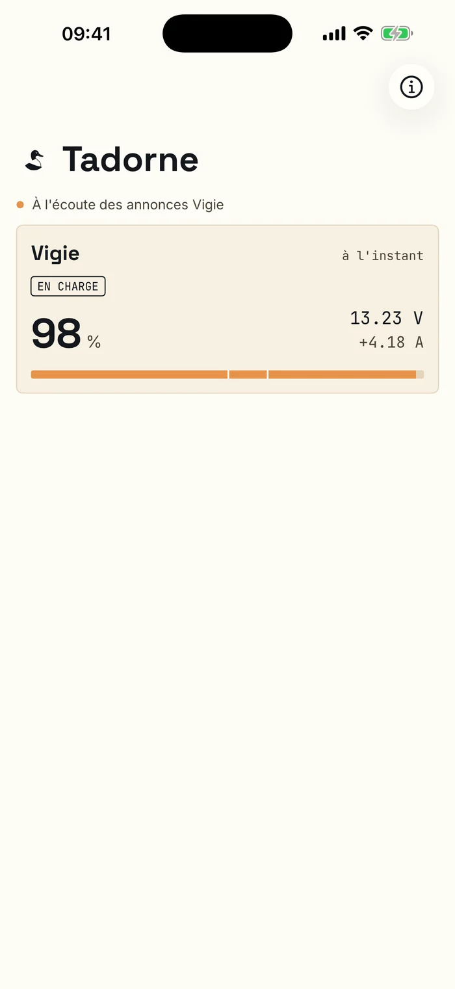
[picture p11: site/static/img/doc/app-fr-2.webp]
Liste des nœuds dans l'application Tadorne.
  
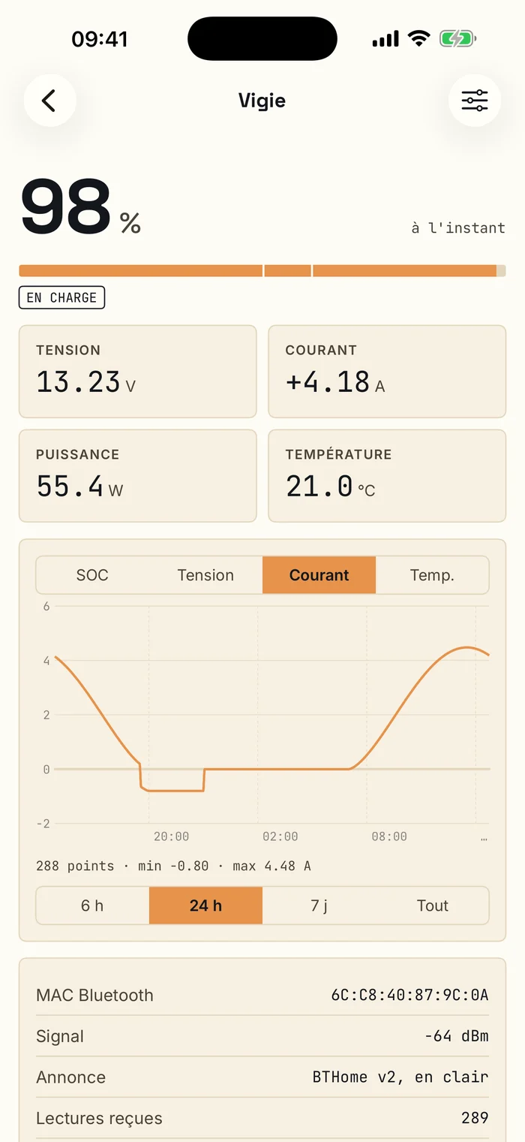
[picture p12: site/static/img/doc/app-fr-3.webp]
Historique du courant dans l'application Tadorne.
  
</div>

<p class="meta">Application Tadorne — fiche d'un nœud, liste des nœuds, historique du courant.</p>

Cette révision de la carte n'embarque **ni LoRa ni LTE** : elle est le poste de
mesure, pas la passerelle Internet. L'arbitrage radio reste ouvert, et la
passerelle viendra s'ajouter au réseau sans modifier la carte.

## État et points ouverts

| Point | État |
|---|---|
| Courant de repos réel | à mesurer à la mise en service — c'est lui qui fixe l'autonomie hivernale |
| Signe du courant au shunt | à valider au premier câblage |
| Antenne en coffret fermé, en fond de cale | point ouvert ; la variante ESP32-WROOM-32UE, à antenne déportée u.FL, se monte sur la même empreinte |
| RS485 du MPPT EPEver | non implanté ; module MAX3485 externe sur J7 |
| Micrologiciel | à publier |
| Nomenclature et procédure d'étalonnage | à venir avec le micrologiciel |

Le banc a validé la compilation des trois environnements, le cycle de sommeil,
le journal et sa reprise après reset, la resynchronisation à 100 % et la
coupure basse tension. La réception réelle des trames ESP-NOW, la réception BLE
et tout ce qui touche à l'INA226 réel restent à vérifier sur la carte.

## Source : le journal

Chaque note du journal est la source de cette page, et le journal fait foi.

{{< log-sources >}}

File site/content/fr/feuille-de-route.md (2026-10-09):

---
title: "Feuille de route"
translationKey: roadmap
url: /fr/feuille-de-route/
type: roadmap
description: "Huit jalons, du banc à une saison à flot."
params:
  milestones:
    - id: "M1"
      title: "Banc validé"
      body: "Chaîne de mesure étalonnée face à une référence ; courant de repos réel mesuré."
    - id: "M2"
      title: "Premières cartes"
      body: "Cartes quatre couches fabriquées, assemblées et mises en service."
    - id: "M3"
      title: "Micrologiciel v1"
      body: "Mesure, état de charge, remontée à distance, chien de garde."
    - id: "M4"
      title: "À flot"
      body: "Nœud installé en amont du coupe-circuit ; une saison entière avec le bateau."
    - id: "M5"
      title: "L'hiver"
      body: "Télémétrie tenue pendant l'hivernage ; budget de consommation respecté."
    - id: "M6"
      title: "Conception ouverte"
      body: "Schéma, scripts, nomenclature et étalonnage publiés."
    - id: "M7"
      title: "Second capteur"
      body: "Courant de charge du hors-bord sur le même bus, sans câble supplémentaire."
    - id: "M8"
      title: "Au-delà de l'énergie"
      body: "Centrale d'attitude et capteur de vent rejoignent le même réseau."
---

La carte est figée d'abord. Tout le reste la rejoint.

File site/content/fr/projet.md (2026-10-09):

---
title: "Le projet"
translationKey: project
url: /fr/projet/
description: "Une carte qui mesure l'énergie du bord, toute l'année."
params:
  eyebrow: "Vigie"
---

## Le problème

Une batterie se vide pendant que le bateau est laissé seul. Les causes habituelles — un instrument resté câblé en direct, un convertisseur qui ne dort jamais, aucune recharge — sont invisibles depuis le quai.

## La démarche

Un nœud, alimenté en amont du coupe-circuit, est la seule chose qui reste vivante : il mesure toute l'installation et rend compte. Tout le reste du bord peut être éteint ou en panne ; la veille continue.

## Un seul point de vérité

Tout le courant passe par un shunt unique, dans le bus négatif. La carte lit la tension à ses bornes en quatre fils — deux pour la charge, deux pour la mesure. Aucun courant de charge ne traverse la carte : rien ne se met en parallèle pour fausser le compte.

## La veille qui ne vide pas

Une veille n'est utile que si elle ne vide pas elle-même la batterie. La conversion est choisie pour son courant de repos, compté en microampères plutôt qu'en milliampères : ce qu'un convertisseur classique prendrait en un mois, Vigie le prend en un an.

## Un réseau, pas un boîtier

Vigie est la passerelle toujours vivante d'un petit réseau radio. Afficheurs, centrale d'attitude, capteur de vent, second capteur de courant : chacun rejoint le réseau au besoin, et chacun peut tomber sans emporter le reste.

## L'horizon

La conception — schéma, implantation, routage — est produite par des scripts versionnés et publiée comme un commun. Les prochaines étapes : un second capteur de courant pour le hors-bord, une centrale d'attitude et un capteur de vent en tête de mât.

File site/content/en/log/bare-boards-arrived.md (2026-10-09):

---
title: "The bare boards have arrived"
translationKey: log/bare-boards-arrived
date: 2026-10-02
description: "Vigie 1.0's printed circuit boards are back from the fab, stencil included."
params:
  tags: ["vigie", "hardware", "fabrication"]
---

Vigie 1.0's bare boards are in. Four-layer, 86 × 54 mm, with the paste stencil
from the same order.

<figure>
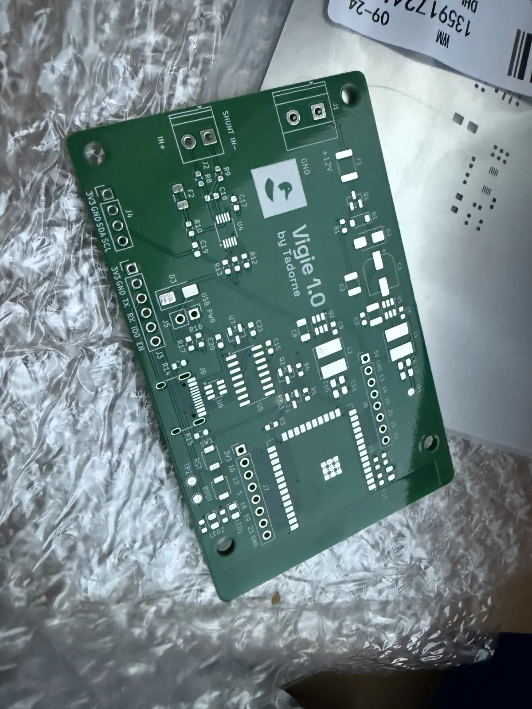
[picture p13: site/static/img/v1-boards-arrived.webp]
Bare Vigie 1.0 boards: outline, silkscreen and Tadorne logo.
  
</figure>

## What came back

The board holds what the file promised. Outline, four M3 holes and both inner
planes are there, and the silkscreen carries enough to wire it without the
schematic at hand: 12 V input and shunt (J1, J2), USB-C and the power jumper,
both expansion headers (J7, J8), plus the **Vigie 1.0 — by Tadorne** logo.

## What is left

Assembly happens on the bench: paste through the stencil, reflow on a hotplate,
then the through-hole parts by iron. One board goes first; the others follow
once it is validated.

Then comes bring-up, with the two measurements that decide the rest: the real
quiescent current, which sets the winter autonomy, and the current sign at the
shunt. The design's open points stay open — antenna in a closed locker, case
clearance, USB-C receptacle overhang.

## Where

- [The Design page](/design/) recalls how the board is produced.
- [KiCad project (ZIP)](/files/vigie-1.0/vigie-1.0-kicad.zip), published under
  CERN-OHL-S v2.
- [Roadmap](/roadmap/) — milestone M2, first boards.

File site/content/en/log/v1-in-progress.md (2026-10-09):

---
title: "V1.0 in progress"
translationKey: log/v1-0
date: 2026-09-21
description: "The first board is on the bench."
params:
  tags: ["vigie", "hardware"]
---

Vigie 1.0, the first board, is on the bench.

<figure>
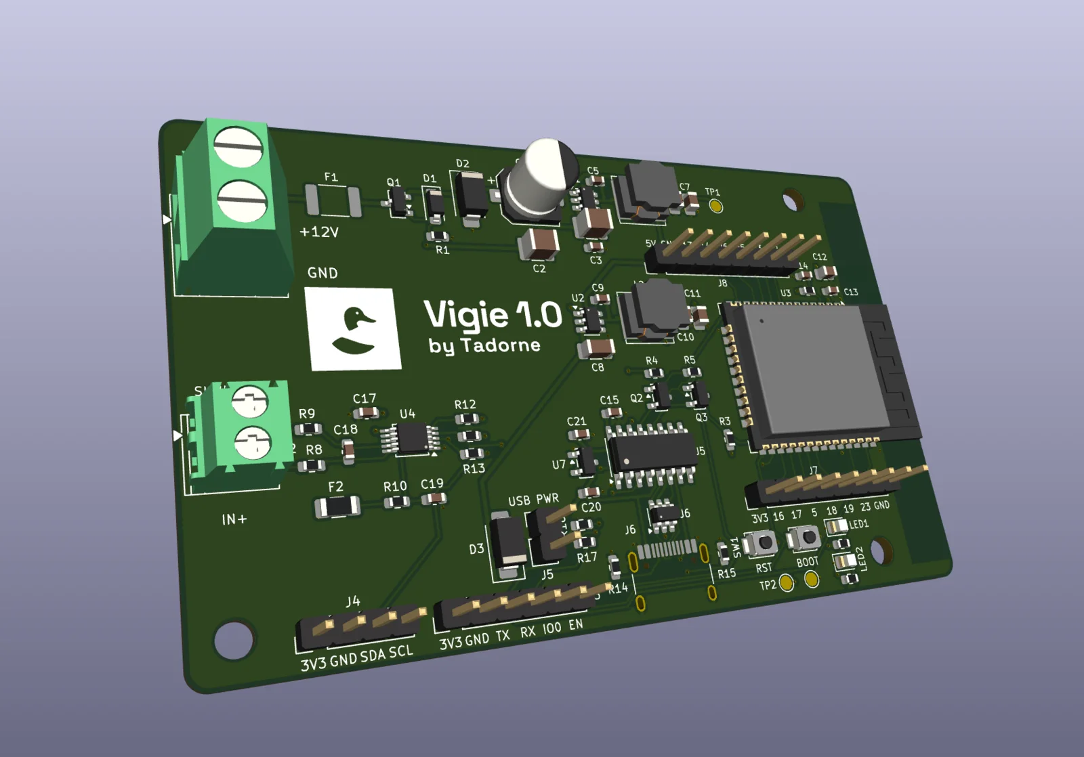
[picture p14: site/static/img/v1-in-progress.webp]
Vigie 1.0 in progress.
  
</figure>

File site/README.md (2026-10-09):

# vigie.tadorne.org — site produit

Site Hugo de **Vigie**, la carte intégrée du nœud énergie, présentée comme un
projet **Tadorne**. Bilingue EN (racine) / FR (`/fr/`), sans thème externe,
sans JavaScript, sans requête tierce.

Structure et système de marque repris du site de Penon ([tadorne-org/penon](https://github.com/tadorne-org/penon)).

## Construire

```console
$ hugo server          # http://localhost:1313/  (FR sur /fr/)
$ hugo --minify        # build de production dans public/
```

Requiert Hugo ≥ 0.146 (testé avec 0.165.0 extended). `public/` n'est pas
versionné.

## Structure

```
hugo.toml              config, langues, menus, params (dont seoIndexable)
i18n/{en,fr}.toml      chaînes d'interface
content/en/            contenu anglais  → /
content/fr/            contenu français → /fr/
assets/css/            tokens.css (marque Tadorne) + fonts.css + main.css
static/fonts/          5 woff2 auto-hébergés
static/img/            visuels du projet (convertis depuis les sources du dépôt)
layouts/               home, page, roadmap, log/, _partials/, _markup/
```

## Publier une info (le journal)

Les deux fichiers doivent porter le **même `translationKey`** — c'est le seul
lien entre les langues :

```console
$ hugo new content/en/log/ma-note.md
$ hugo new content/fr/journal/ma-note.md
```

```yaml
---
title: "Titre"
translationKey: log/ma-note
date: 2026-09-15
description: "Une ou deux phrases : listes, RSS et og:description."
params:
  tags: ["vigie"]
---
```

Le fil RSS est sur `/log/index.xml` et `/fr/journal/index.xml`.

Une note publiée apparaît aussi dans la liste « Source : le journal » de la page
Documentation : le shortcode `log-sources` relit la section du journal à chaque
build, sans qu'il y ait à toucher la page.

## Sources des gabarits

Le site reprend à l'identique la structure, la feuille de style et les partiels
du site de Penon. Les adaptations propres à Vigie sont :

- le titre, le `baseURL` (`https://vigie.tadorne.org/`), les descriptions ;
- le mot de marque dans l'en-tête (`vigie`) et le nom du bundle CSS
  (`css/vigie.css`, dans `layouts/_partials/head.html`) ;
- la page « Conception » (`/design/`, `/fr/conception/`) qui remplace la page
  « Financement » ;
- la page « Documentation » (`/documentation/`, `/fr/documentation/`), la
  documentation technique illustrée de Vigie 1.0 (architecture, carte, mesure,
  micrologiciel, réseau), avec un disclaimer « travail en cours » en tête et la
  liste des notes générée par le shortcode `log-sources` ;
- les figures de la page, dans `static/img/doc/` : rendus et plans de la carte
  (`pcb/build/`), montage au bus négatif (figure d'étude), captures de l'app
  Tadorne (FR et EN), et un schéma-bloc de la carte généré en SVG
  (`vigie-blocs-fr.svg`, `vigie-blocs-en.svg`). Le dossier garde aussi les
  figures d'étude que la page n'utilise pas encore (synoptique, hivernage,
  coffret, support de panneau), converties depuis les sources du dépôt ;
- le contenu, rédigé à partir de `docs/`, `pcb/README.md`, `firmware/README.md`
  et `ios/README.md` du dépôt.

Les figures d'étude datent de l'empilage de modules (INA228, LilyGo) et sont
légendées comme telles ; la documentation décrit la carte intégrée.

## Indexation : ouverte

`params.seoIndexable = true` dans `hugo.toml` → aucune balise `robots` sur les
pages, `robots.txt` en `Allow: /` et sitemap annoncé.

Le site était en divulgation restreinte jusqu'à la mise au banc de la carte.
Repasser le paramètre à `false` referme tout d'un coup : `noindex, nofollow,
noarchive` sur chaque page et `Disallow: /`.

## Déploiement

`hugo --minify` produit un `public/` statique — n'importe quel hébergeur
statique convient. `netlify.toml` est fourni.
Sur Netlify, le répertoire de base (*Base directory*) est `site`.

`baseURL` vaut `https://vigie.tadorne.org/` ; le surcharger au besoin avec
`hugo --baseURL https://exemple/`.

## Licences

- Contenu (`content/`, images, vidéos, modèles 3D) : [CC BY-SA 4.0](LICENSE-CONTENT).
- Gabarits, CSS, JavaScript et configuration : [MIT](LICENSE).
- Polices (`static/fonts/`) : SIL Open Font License 1.1, propriété de leurs auteurs.
- `static/files/` : fichiers de fabrication publiés avec leur propre licence
  (CERN-OHL-S v2, texte joint dans chaque dossier).

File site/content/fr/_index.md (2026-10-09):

---
title: "Vigie"
translationKey: home
description: "Un nœud d'énergie toujours vivant pour petits voiliers : une carte qui mesure la batterie, veille tout l'hiver et rend compte depuis la cale. Un projet Tadorne."
params:
  hero:
    eyebrow: "Un projet Tadorne"
    lead: "La vigie de la batterie. Une carte qui mesure l'énergie à bord, veille à quelques microampères et rend compte depuis la cale — toute l'année, coupe-circuit ouvert."
    ctas:
      - label: "Le projet"
        url: "/fr/projet/"
      - label: "La conception"
        url: "/fr/conception/"
      - label: "Kit — bientôt disponible"
        url: "/fr/interet/"
        solid: true
  video:
    mp4: "/video/vigie-fr.mp4"
    webm: "/video/vigie-fr.webm"
    poster: "/video/vigie-fr-poster.jpg"
    caption: "Vigie 1.0 : la vue éclatée, puis la carte à bord — shunt, paire Kelvin, Bluetooth LE."
  figures:
    - label: "Carte"
      value: "86 × 54 mm"
    - label: "Couches"
      value: "4"
    - label: "Courant de veille"
      value: "22 µA"
    - label: "Courant mesuré"
      value: "100 A"
    - label: "Régime"
      value: "Toute l'année"
  notes:
    - title: "Un seul point de vérité"
      body: "Tout le courant passe par le shunt ; la carte ne fait que le lire. Aucun chemin parallèle, aucune erreur silencieuse."
    - title: "Toujours vivante"
      body: "Alimentée en amont du coupe-circuit, c'est le seul module qui passe l'hiver."
    - title: "Fabriquée par scripts"
      body: "Schéma, implantation et routage sont régénérés par du code versionné, pas dessinés à la main."
  closing:
    title: "Rejoindre Vigie"
    body: "Bêta-testeurs et contributeurs recherchés. La carte est sur le banc, la saison à flot suivra."
    url: "mailto:contact@tadorne.org?subject=Vigie%20%E2%80%94%20b%C3%AAta-test%20%2F%20contribution&body=Bonjour%2C%0A%0AJe%20souhaite%20m%27impliquer%20dans%20Vigie.%0A%0ACe%20que%20je%20peux%20apporter%20%3A%0A-%0A%0ACe%20que%20je%20cherche%20%3A%0A-%0A%0AMerci."
    label: "Écrire"
---

L'état de la batterie lu au shunt, et une veille tenue toute l'année.

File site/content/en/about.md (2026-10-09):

---
title: "About"
translationKey: about
url: /about/
description: "Vigie is a Tadorne project."
---

**Tadorne** — *duck engineering* — designs and publishes open hardware: electronics, mechanics, firmware, silicon. Vigie is one of its projects.

Everything published is signed with a single GPG key, anchored in the DNS of `tadorne.org`:

<code class="fingerprint">5420 08E3 53EC A628 B4D6  ACAD 8C03 243A FF69 5BF7</code>

[How to verify a publication](https://tadorne.org/verify/) · `contact@tadorne.org`

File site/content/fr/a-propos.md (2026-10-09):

---
title: "À propos"
translationKey: about
url: /fr/a-propos/
description: "Vigie est un projet Tadorne."
---

**Tadorne** — *duck engineering* — conçoit et publie du matériel libre : électronique, mécanique, micrologiciel, silicium. Vigie est l'un de ses projets.

Tout ce qui est publié est signé par une clé GPG unique, ancrée dans le DNS de `tadorne.org` :

<code class="fingerprint">5420 08E3 53EC A628 B4D6  ACAD 8C03 243A FF69 5BF7</code>

[Comment vérifier une publication](https://tadorne.org/verifier/) · `contact@tadorne.org`

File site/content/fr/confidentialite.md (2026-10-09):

---
title: "Confidentialité — app Tadorne"
translationKey: privacy
url: /fr/confidentialite/
description: "L'app iPhone Tadorne ne collecte rien, n'envoie rien et n'a pas de compte."
---

L'app iPhone **Tadorne** affiche les mesures que les nœuds Vigie annoncent
en Bluetooth Low Energy.

- **Aucune donnée n'est collectée.** Ni compte, ni mesure d'audience, ni
  publicité, ni pistage, ni SDK tiers.
- **Rien ne quitte le téléphone.** L'app ne fait aucune requête réseau. Elle
  écoute seulement les annonces Bluetooth, sans jamais se connecter à un
  appareil.
- **Ce qui est gardé, et où.** Les mesures reçues app ouverte, les noms
  donnés aux nœuds et leurs adresses Bluetooth restent dans le stockage
  propre de l'app, sur le téléphone. Les clés de chiffrement BTHome saisies
  sont rangées dans le trousseau d'iOS. Oublier un nœud, ou supprimer l'app,
  les efface.
- **L'autorisation Bluetooth** ne sert qu'à recevoir les annonces de Vigie.
- **Export.** Un export CSV n'est créé qu'à la demande, et ne va que là où
  l'utilisateur l'envoie.

Questions&nbsp;: `contact@tadorne.org`

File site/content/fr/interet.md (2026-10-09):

---
title: "Manifester son intérêt"
translationKey: interest
url: /fr/interet/
eyebrow: "Vigie 1.0 — pré-série"
description: "Ni vente, ni pré-commande : une liste de personnes intéressées, pour décider si une petite série a un sens."
figures:
  - label: "Carte"
    value: "86 × 54 mm"
  - label: "Mesure"
    value: "INA226 · shunt 100 A"
  - label: "Courant de veille"
    value: "22 µA"
  - label: "État"
    value: "Banc"
---

**Vigie** est la carte du nœud d'énergie : un ESP32 et un INA226 qui mesurent la batterie d'un petit voilier, en amont du coupe-circuit, à quelques microampères près — de quoi tenir un hivernage entier sans vider la batterie.

Vigie 1.0 arrive sur le banc. Quelques cartes seront assemblées au-delà du besoin du bord. Avant d'en faire un produit — et avant d'engager les démarches de conformité qu'une mise en vente impose — il reste une question à trancher : **cet objet intéresse-t-il quelqu'un d'autre que son auteur ?**

Cette page sert à y répondre. Elle ne vend rien.

{{< callout title="Ce que cette page n'est pas" >}}
- Ce n'est **pas une pré-commande** : aucun paiement, aucun engagement, aucune date promise.
- Ce n'est **pas une réservation** : le nombre de cartes disponibles n'est pas encore connu.
- Ce n'est **pas un formulaire** : le message part du logiciel de messagerie du visiteur. Aucun script, aucun cookie, aucune donnée transmise à un tiers — comme partout sur ce site.
{{< /callout >}}

## Répondre

Le lien ci-dessous ouvre un message pré-rempli. Six lignes suffisent. Le message part directement du logiciel de messagerie, à l'adresse `contact@tadorne.org` ; rien ne transite par le site.

<p style="margin-top:1.5rem"><a class="btn btn--solid" href="mailto:contact@tadorne.org?subject=Vigie%201.0%20%3A%20manifestation%20d%27int%C3%A9r%C3%AAt&amp;body=Bateau%20%28mod%C3%A8le%2C%20longueur%29%20%3A%0D%0APort%20d%27attache%20et%20zone%20de%20navigation%20%3A%0D%0AInstallation%20actuelle%20%28batterie%2C%20charge%2C%20shunt%20%C3%A9ventuel%29%20%3A%0D%0ACe%20qui%20int%C3%A9resse%20%28carte%20seule%20%2F%20kit%20carte%20%2B%20shunt%20%2B%20entretoises%20%2F%20suivre%20le%20projet%29%20%3A%0D%0AHivernage%20%C3%A0%20bord%20%3A%20oui%20%2F%20non%0D%0ALangue%20souhait%C3%A9e%20pour%20la%20documentation%20%3A%20fran%C3%A7ais%20%2F%20anglais">Écrire à Tadorne</a></p>

Si le lien ne s'ouvre pas, écrire à `contact@tadorne.org` en reprenant ces six lignes :

1. Bateau — modèle, longueur
2. Port d'attache et zone de navigation
3. Installation actuelle — batterie, charge, shunt éventuel
4. Ce qui intéresse — carte seule, kit (carte + shunt + entretoises), ou simplement suivre le projet
5. Hivernage à bord — oui ou non
6. Langue souhaitée pour la documentation — français ou anglais

## La suite

Chaque message reçoit une réponse. Les personnes de cette liste sont prévenues en premier si une petite série se décide, et avant toute publication.

Les réponses servent uniquement à décider de la suite du projet. Elles ne sont ni revendues ni transmises, et un simple message suffit à les faire supprimer.

L'avancement est tenu à jour dans [la feuille de route](/fr/feuille-de-route/) et dans [le journal](/fr/journal/).

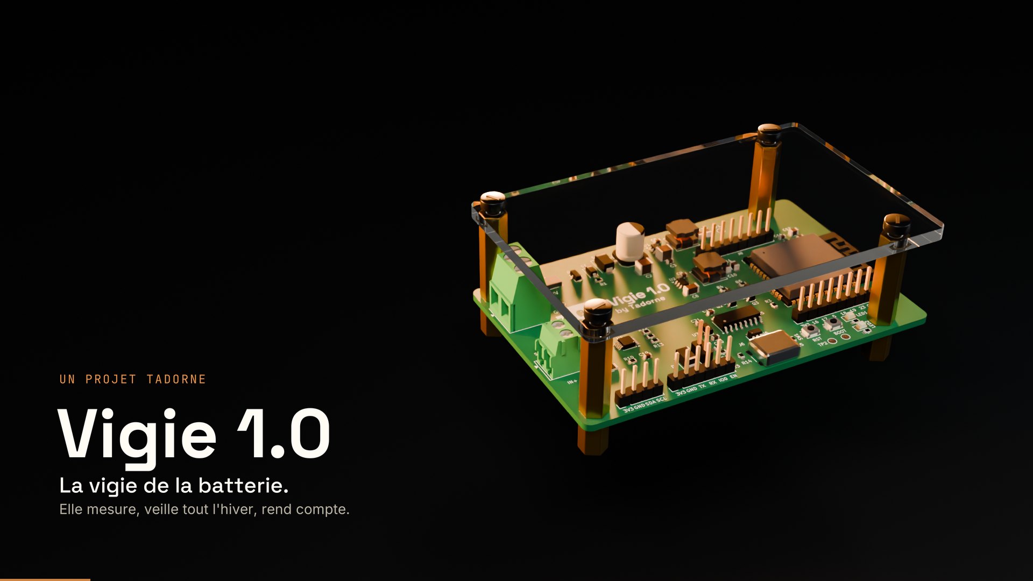
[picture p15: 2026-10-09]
site/static/video/vigie-fr-poster.jpg

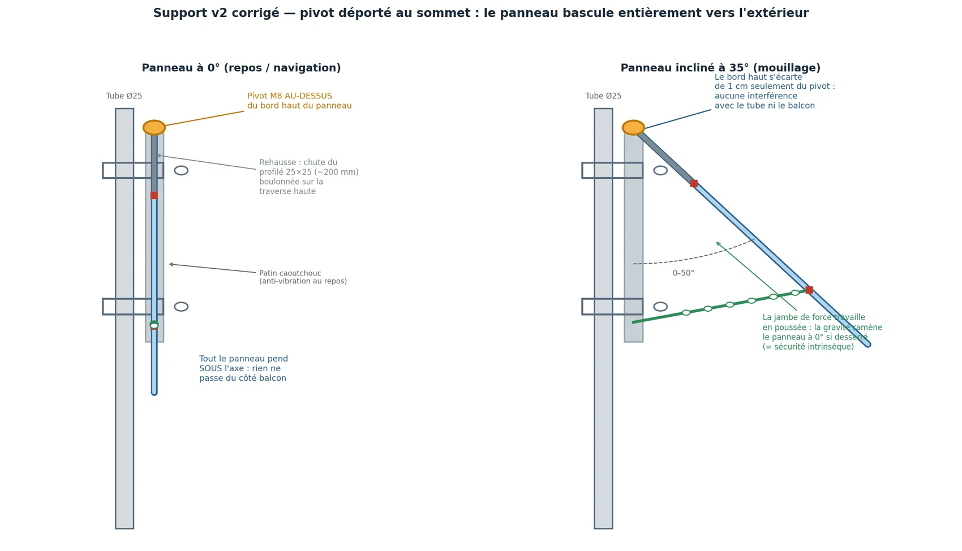
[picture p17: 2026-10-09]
site/static/img/doc/support-panneau.webp

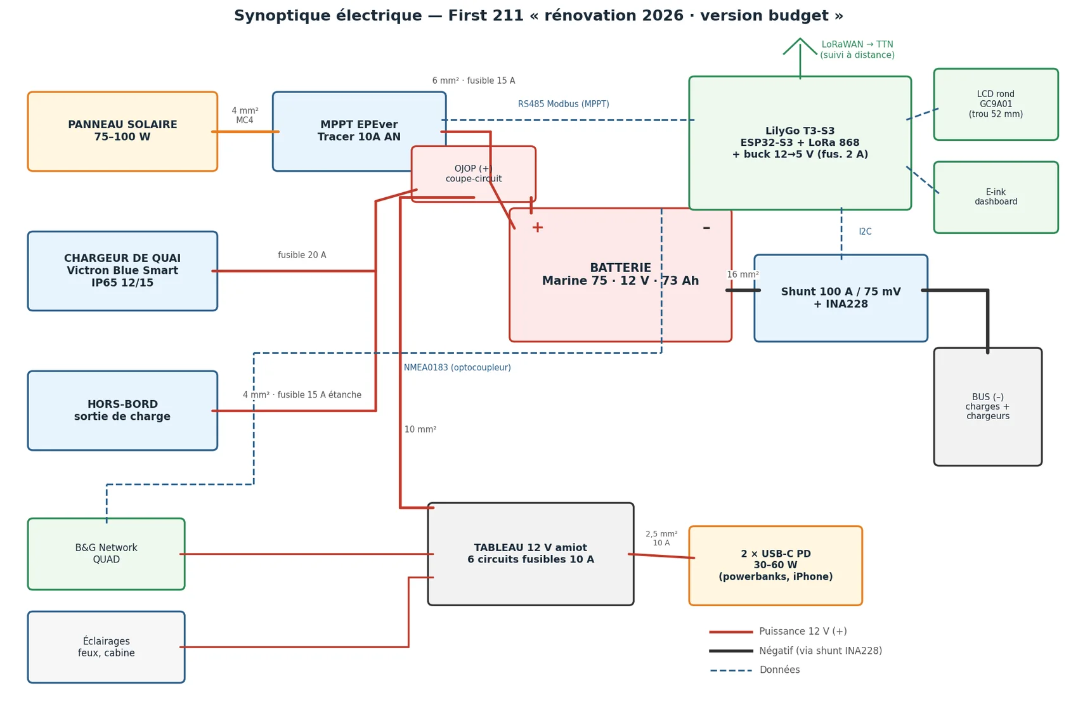
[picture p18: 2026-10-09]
site/static/img/doc/synoptique.webp

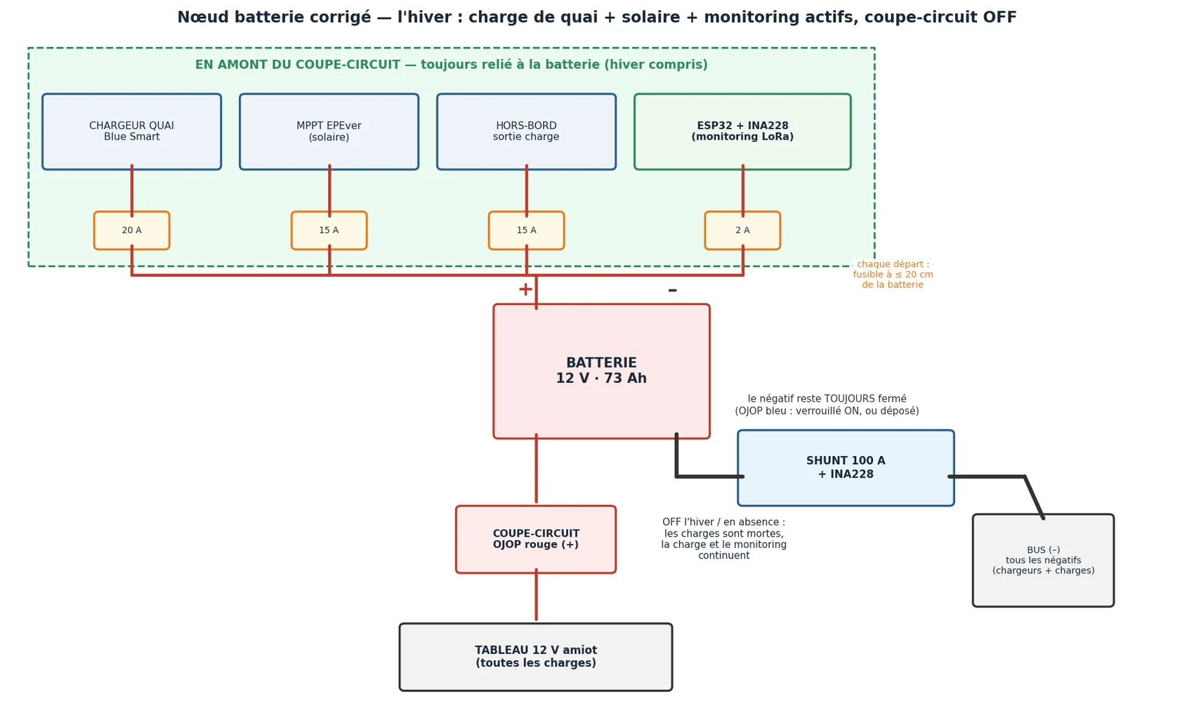
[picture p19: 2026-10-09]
site/static/img/doc/hiver.webp

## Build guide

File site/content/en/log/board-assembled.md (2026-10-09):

---
title: "Board assembled, first tests pass"
translationKey: log/board-assembled
date: 2026-10-07
description: "Components are on the first board; the microcontroller, the INA226 and the admin page all answer. The 12 V battery is next."
params:
  tags: ["vigie", "hardware", "firmware"]
---

The components are on the board. The first board of the batch is assembled —
paste through the stencil, reflow on a hotplate, then the through-hole parts by
iron — and it survived its first power-up.

<figure>
  Assembled Vigie 1.0 board, powered over USB-C, on the bench.
</figure>

## What answered

- **3.3 V is there.** The green LED lights up; the board breaks its silence.
- **USB-C and the CH340C do their job.** The board flashes like a devkit, with
  no external probe or programmer.
- **The firmware runs.** The ESP32 opens its access point, serves its admin
  page and reports its version number.
- **The INA226 answers on I2C.** The "Sensor" line reads `INA226 (continuous)`
  rather than the simulator: the measurement chain is alive.

<figure>
  Vigie 1.0 dashboard, served from the board's own access point.
</figure>

Powered from USB and with no shunt, the current columns mean nothing yet: the
**109.23 A** on screen is the INA226's full scale (81.92 mV across a 0.75 mΩ
shunt), with the input left floating. The battery is what will give those
numbers a meaning.

## Next: the 12 V battery

Next step, measurements on a battery: the **real quiescent current**, the one
that sets the winter autonomy, the **current sign at the shunt**, and
calibration against a reference. The bench then closes milestone M1, and
bring-up closes M2 with it.

## Where

- [The Design page](/design/) recalls how the board is produced.
- [Roadmap](/roadmap/) — milestones M1 and M2.
- [KiCad project (ZIP)](/files/vigie-1.0/vigie-1.0-kicad.zip), published under
  CERN-OHL-S v2.

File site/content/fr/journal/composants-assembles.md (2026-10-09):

---
title: "Carte montée, premiers tests concluants"
translationKey: log/board-assembled
date: 2026-10-07
description: "Les composants sont montés sur la première carte ; le microcontrôleur, l'INA226 et la page d'administration répondent. Reste la batterie 12 V."
params:
  tags: ["vigie", "matériel", "micrologiciel"]
---

Les composants sont montés sur la carte. La première carte du lot est assemblée
— pâte au pochoir, refusion sur plaque, puis les traversants au fer — et elle a
tenu sa première mise sous tension.

<figure>
  Carte Vigie 1.0 assemblée, alimentée par l'USB-C, sur le banc.
</figure>

## Ce qui a répondu

- **Le 3,3 V est là.** La LED verte s'allume, la carte sort de son silence.
- **L'USB-C et le CH340C font leur travail.** La carte se flashe comme une
  devkit, sans sonde ni programmateur externe.
- **Le micrologiciel tourne.** L'ESP32 ouvre son point d'accès, sert sa page
  d'administration et affiche son numéro de version.
- **L'INA226 répond sur l'I2C.** La ligne « Capteur » annonce `INA226
  (continu)` et non le simulateur : la chaîne de mesure est vivante.

<figure>
  Tableau de bord de Vigie 1.0, servi depuis le point d'accès de la carte.
</figure>

Alimentée par l'USB et sans shunt, les colonnes de courant ne veulent encore
rien dire : les **109,23 A** affichés sont le fond d'échelle de l'INA226
(81,92 mV sur un shunt de 0,75 mΩ), entrée laissée en l'air. C'est la batterie
qui donnera un sens à ces chiffres.

## La suite : la batterie 12 V

Prochaine étape, les mesures sur batterie : le **courant de repos réel**, celui
qui fixe l'autonomie hivernale, le **sens du courant au shunt**, et
l'étalonnage face à une référence. Le banc ferme alors le jalon M1, et la mise
en service le M2 avec lui.

## Où

- [La page Conception](/fr/conception/) rappelle comment la carte est produite.
- [Feuille de route](/fr/feuille-de-route/) — jalons M1 et M2.
- [Projet KiCad (ZIP)](/files/vigie-1.0/vigie-1.0-kicad.zip), publié sous
  CERN-OHL-S v2.

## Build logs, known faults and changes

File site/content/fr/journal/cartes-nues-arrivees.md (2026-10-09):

---
title: "Les cartes nues sont arrivées"
translationKey: log/bare-boards-arrived
date: 2026-10-02
description: "Les circuits imprimés de Vigie 1.0 sont sortis de fonderie, pochoir compris."
params:
  tags: ["vigie", "matériel", "fabrication"]
---

Le lot de cartes nues de **Vigie 1.0** est arrivé. Circuits imprimés quatre
couches de 86 × 54 mm, avec le pochoir de dépôt de pâte qui faisait partie de
la même commande.

<figure>
  Cartes nues Vigie 1.0, contour, sérigraphie et logo Tadorne.
</figure>

## Ce que la fonderie a rendu

La carte tient ce que le fichier annonçait. Le contour, les quatre trous M3 et
les deux plans internes sont au rendez-vous, et la sérigraphie porte de quoi
câbler sans avoir le schéma sous les yeux : entrée 12 V et shunt (J1, J2),
USB-C et cavalier d'alimentation, les deux barrettes d'extension (J7, J8),
plus le logo **Vigie 1.0 — by Tadorne**.

## Ce qui reste à faire

L'assemblage se fera à l'établi : pâte au pochoir, refusion sur plaque, puis
les traversants au fer. Une seule carte passe en premier ; les autres suivent
une fois celle-là validée.

Vient ensuite la mise en service, avec les deux mesures qui décident de la
suite : le courant de repos réel, qui fixe l'autonomie hivernale, et le signe
du courant au shunt. Les points ouverts du dossier restent ouverts — antenne en
fond de cale, tenue du coffret, recul de l'embase USB-C.

## Où

- [La page Conception](/fr/conception/) rappelle comment la carte est produite.
- [Projet KiCad (ZIP)](/files/vigie-1.0/vigie-1.0-kicad.zip), publié sous
  CERN-OHL-S v2.
- [Feuille de route](/fr/feuille-de-route/) — jalon M2, premières cartes.

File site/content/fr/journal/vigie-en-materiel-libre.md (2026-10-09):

---
title: "Vigie passe en matériel libre"
translationKey: log/vigie-open-hardware
date: 2026-09-28
description: "Le schéma et la carte quatre couches de Vigie 1.0 sont publiés sous CERN-OHL-S v2."
params:
  tags: ["vigie", "matériel", "licence"]
---

Le projet KiCad de **Vigie 1.0** est publié sous la licence matérielle
**CERN-OHL-S v2**. Schéma, carte quatre couches et bibliothèque de symboles : le
minimum nécessaire pour ouvrir, étudier et refabriquer la carte est
téléchargeable dès maintenant.

## Ce qui est publié

| Élément | Format |
|---|---|
| Schéma | KiCad |
| Circuit imprimé | KiCad, quatre couches, routé |
| Bibliothèque | symbole `CH340C_3V3` du projet |

Le projet s'ouvre tel quel dans KiCad 10. La nomenclature n'est pas fournie à
part : elle s'exporte directement du schéma, avec les outils de KiCad.

## Responsabilité et limites

- **La carte n'est pas éprouvée.** Les tests d'intégration sont en cours, et le
  courant de repos réel n'est pas encore mesuré. Le dossier est publié dans son
  état, points ouverts compris — antenne en fond de cale, orientation du shunt
  à valider.
- **Aucune garantie.** Le texte de la licence est explicite : la source est
  fournie telle quelle. Une carte qui commute 12 V à bord engage la sécurité de
  celui qui la câble.
- **Le micrologiciel reste à publier.** Cette archive couvre le matériel ; le
  code qui lit l'INA226 et tient l'hivernage suivra sa propre licence.

## Où

- [Projet KiCad (ZIP)](/files/vigie-1.0/vigie-1.0-kicad.zip)
- [Signature détachée (`.asc`)](/files/vigie-1.0/vigie-1.0-kicad.zip.asc)
- [Horodatage FreeTSA (`.tsr`)](/files/vigie-1.0/vigie-1.0-kicad.zip.tsr)
- [Texte de la licence CERN-OHL-S v2](/files/vigie-1.0/LICENSE-CERN-OHL-S-2.0.txt)

L'archive est signée avec la clé de publication Tadorne ; l'empreinte figure
dans le pied de page. Elle est aussi horodatée par FreeTSA (RFC 3161).

La source publiée fait autorité ; elle est aussi décrite sur [la page
Conception](/fr/conception/), qui rappelle comment la carte est produite.

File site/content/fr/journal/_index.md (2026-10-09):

---
title: "Journal"
translationKey: log
type: log
description: "Notes de travail et avancement, au fil de l'eau."
cascade:
  type: log
---

Réalisé puis publié.

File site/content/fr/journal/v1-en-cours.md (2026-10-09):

---
title: "V1.0 en cours"
translationKey: log/v1-0
date: 2026-09-21
description: "La première carte est sur le banc."
params:
  tags: ["vigie", "matériel"]
---

Vigie 1.0, la première carte, est sur le banc.

<figure>
  Vigie 1.0 en cours.
</figure>

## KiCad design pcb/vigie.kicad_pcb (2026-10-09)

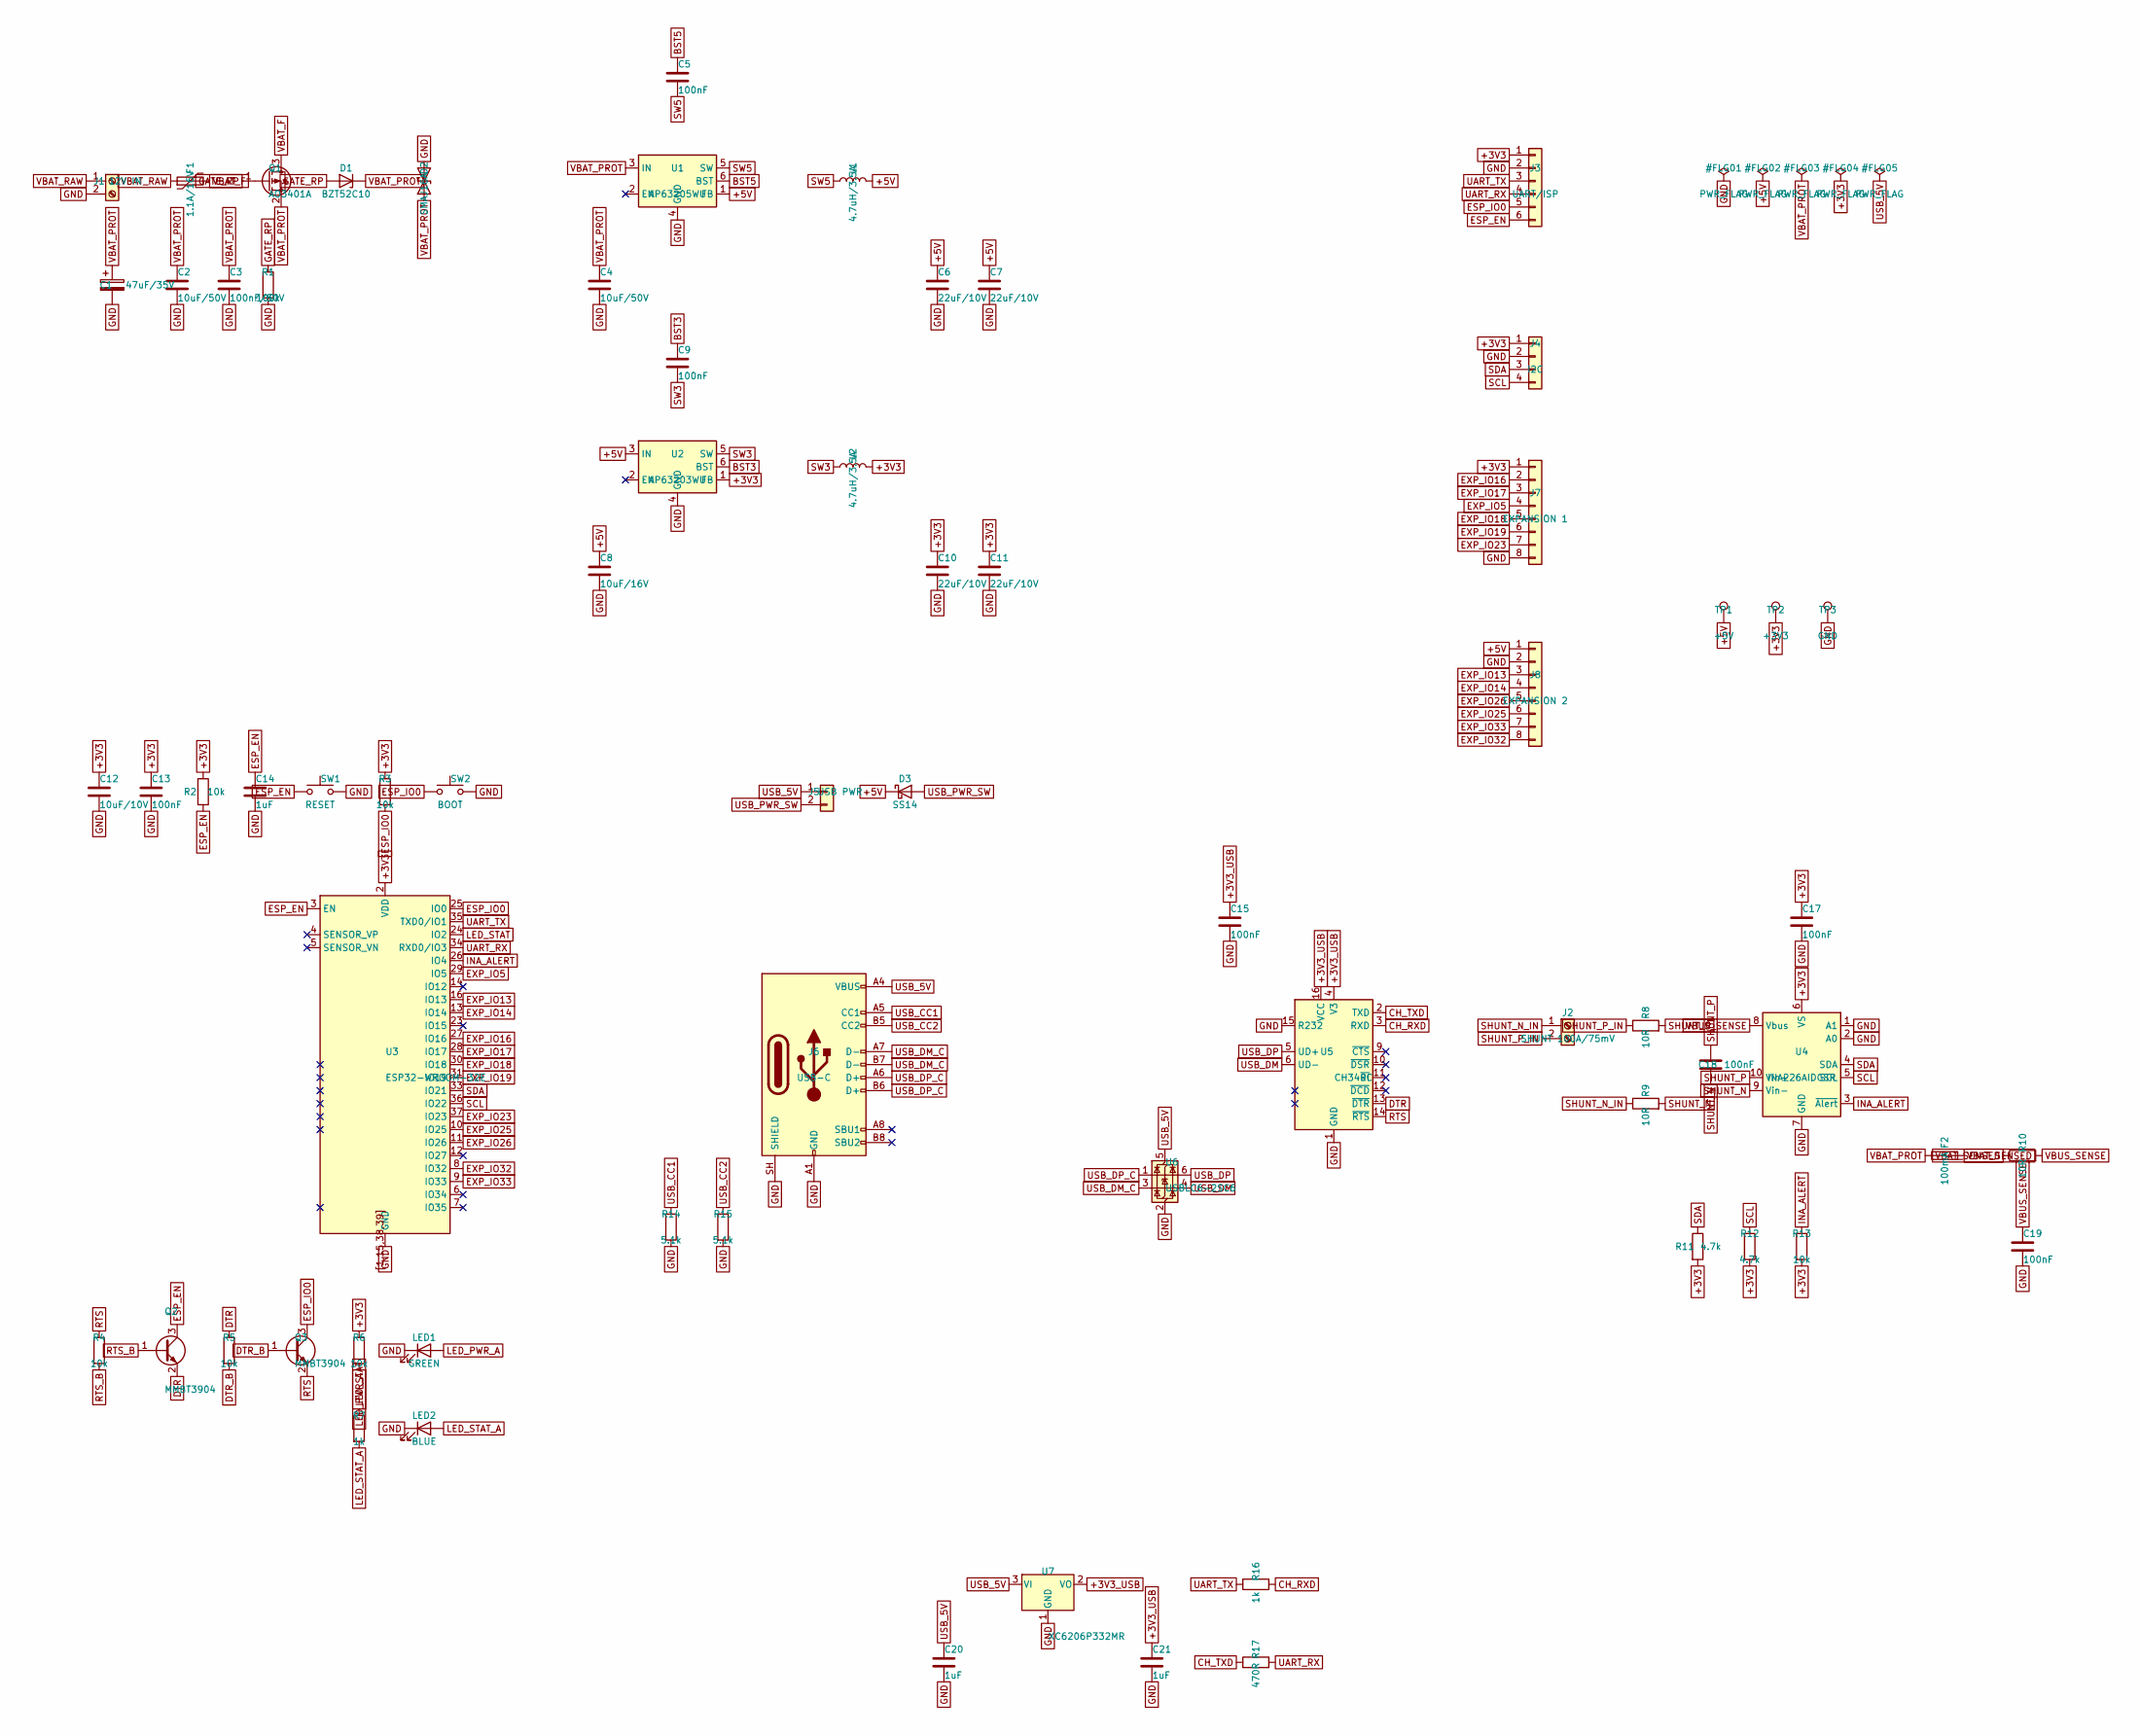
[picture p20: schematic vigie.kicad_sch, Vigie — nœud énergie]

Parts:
C1: 47uF/35V; CP_Elec_6.3x7.7
C2, C4: 10uF/50V; C_1210_3225Metric
C3: 100nF/50V; C_0603_1608Metric
C5, C9, C13, C15, C17, C18, C19: 100nF; C_0603_1608Metric
C6, C7, C10, C11: 22uF/10V; C_0805_2012Metric
C8: 10uF/16V; C_1206_3216Metric
C12: 10uF/10V; C_0805_2012Metric
C14, C20, C21: 1uF; C_0603_1608Metric
D1: BZT52C10; D_SOD-123
D2: SMAJ16A; D_SMA
D3: SS14; D_SMA
F1: 1.1A/16V; Fuse_1812_4532Metric
F2: 100mA; Fuse_1206_3216Metric
J1: 12V IN; TerminalBlock_Phoenix_MKDS-1,5-2-5.08_1x02_P5.08mm_Horizont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
J2: SHUNT 100A/75mV; TerminalBlock_Phoenix_PT-1,5-2-3.5-H_1x02_P3.50mm_Horizontal
J3: UART/ISP; PinHeader_1x06_P2.54mm_Vertical
J4: I2C; PinHeader_1x04_P2.54mm_Vertical
J5: USB PWR; PinHeader_1x02_P2.54mm_Vertical
J6: USB-C; USB_C_Receptacle_HRO_TYPE-C-31-M-12
J7: EXPANSION 1; PinHeader_1x08_P2.54mm_Vertical
J8: EXPANSION 2; PinHeader_1x08_P2.54mm_Vertical
L1, L2: 4.7uH/3.5A; L_Bourns_SRN6045TA
LED1: GREEN; LED_0805_2012Metric
LED2: BLUE; LED_0805_2012Metric
Q1: AO3401A; SOT-23
Q2, Q3: MMBT3904; SOT-23
R1: 100k; R_0603_1608Metric
R2, R3, R4, R5, R6, R13: 10k; R_0603_1608Metric
R7, R16: 1k; R_0603_1608Metric
R8, R9, R10: 10R; R_0603_1608Metric
R11, R12: 4.7k; R_0603_1608Metric
R14, R15: 5.1k; R_0603_1608Metric
R17: 470R; R_0603_1608Metric
SW1: RESET; SW_SPST_B3U-1000P
SW2: BOOT; SW_SPST_B3U-1000P
TP1: +5V; TestPoint_Pad_D1.5mm
TP2: +3V3; TestPoint_Pad_D1.5mm
TP3: GND; TestPoint_Pad_D1.5mm
U1: AP63205WU; TSOT-23-6
U2: AP63203WU; TSOT-23-6
U3: ESP32-WROOM-32E
U4: INA226AIDGSR; TSSOP-10_3x3mm_P0.5mm
U5: CH340C; SOIC-16_3.9x9.9mm_P1.27mm
U6: USBLC6-2SC6; SOT-23-6
U7: XC6206P332MR; SOT-23

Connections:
+3V3: C10.1, C11.1, C12.1, C13.1, C17.1, J3.1, J4.1, J7.1, L2.2, R2.1, R3.1, R6.1, R11.2, R12.2, R13.2, TP2.1, U2.1 (FB), U3.2 (VDD), U4.6 (VS)
+3V3_USB: C15.1, C21.1, U5.4 (V3), U5.16 (VCC), U7.2 (VO)
+5V: C6.1, C7.1, C8.1, D3.1 (K), J8.1, L1.2, TP1.1, U1.1 (FB), U2.3 (IN)
BST3: C9.1, U2.6 (BST)
BST5: C5.1, U1.6 (BST)
CH_RXD: R16.2, U5.3 (RXD)
CH_TXD: R17.1, U5.2 (TXD)
DTR: Q2.2 (E), R5.1, U5.13 (~DTR)
DTR_B: Q3.1 (B), R5.2
ESP_EN: C14.1, J3.6, Q2.3 (C), R2.2, SW1.1, U3.3 (EN)
ESP_IO0: J3.5, Q3.3 (C), R3.2, SW2.1, U3.25 (IO0)
EXP_IO5: J7.4, U3.29 (IO5)
EXP_IO13: J8.3, U3.16 (IO13)
EXP_IO14: J8.4, U3.13 (IO14)
EXP_IO16: J7.2, U3.27 (IO16)
EXP_IO17: J7.3, U3.28 (IO17)
EXP_IO18: J7.5, U3.30 (IO18)
EXP_IO19: J7.6, U3.31 (IO19)
EXP_IO23: J7.7, U3.37 (IO23)
EXP_IO25: J8.6, U3.10 (IO25)
EXP_IO26: J8.5, U3.11 (IO26)
EXP_IO32: J8.8, U3.8 (IO32)
EXP_IO33: J8.7, U3.9 (IO33)
GATE_RP: D1.2 (A), Q1.1 (G), R1.1
GND: C1.2, C2.2, C3.2, C4.2, C6.2, C7.2, C8.2, C10.2, C11.2, C12.2, C13.2, C14.2, C15.2, C17.2, C19.2, C20.2, C21.2, D2.2 (A2), J1.2, J3.2, J4.2, J6.A1 (GND), J6.A12 (GND), J6.B1 (GND), J6.B12 (GND), J6.SH (SHIELD), J7.8, J8.2, LED1.1 (K), LED2.1 (K), R1.2, R14.2, R15.2, SW1.2, SW2.2, TP3.1, U1.4 (GND), U2.4 (GND), U3.1, U3.15, U3.38, U3.39, U3.[1,15,38,39] (GND), U4.1 (A1), U4.2 (A0), U4.7 (GND), U5.1 (GND), U5.15 (R232), U6.2 (GND), U7.1 (GND)
INA_ALERT: R13.1, U3.26 (IO4), U4.3 (~Alert)
LED_PWR_A: LED1.2 (A), R6.2
LED_STAT: R7.1, U3.24 (IO2)
LED_STAT_A: LED2.2 (A), R7.2
RTS: Q3.2 (E), R4.1, U5.14 (~RTS)
RTS_B: Q2.1 (B), R4.2
SCL: J4.4, R12.1, U3.36 (IO22), U4.5 (SCL)
SDA: J4.3, R11.1, U3.33 (IO21), U4.4 (SDA)
SHUNT_N: C18.2, R9.2, U4.9 (Vin-)
SHUNT_N_IN: J2.1, R9.1
SHUNT_P: C18.1, R8.2, U4.10 (Vin+)
SHUNT_P_IN: J2.2, R8.1
SW3: C9.2, L2.1, U2.5 (SW)
SW5: C5.2, L1.1, U1.5 (SW)
UART_RX: J3.4, R17.2, U3.34 (RXD0/IO3)
UART_TX: J3.3, R16.1, U3.35 (TXD0/IO1)
USB_5V: C20.1, J5.1, J6.A4 (VBUS), J6.A9 (VBUS), J6.B4 (VBUS), J6.B9 (VBUS), U6.5 (VBUS), U7.3 (VI)
USB_CC1: J6.A5 (CC1), R14.1
USB_CC2: J6.B5 (CC2), R15.1
USB_DM: U5.6 (UD-), U6.4 (I/O2)
USB_DM_C: J6.A7 (D-), J6.B7 (D-), U6.3 (I/O2)
USB_DP: U5.5 (UD+), U6.6 (I/O1)
USB_DP_C: J6.A6 (D+), J6.B6 (D+), U6.1 (I/O1)
USB_PWR_SW: D3.2 (A), J5.2
VBAT_F: F1.2, Q1.3 (D)
VBAT_PROT: C1.1, C2.1, C3.1, C4.1, D1.1 (K), D2.1 (A1), F2.1, Q1.2 (S), U1.3 (IN)
VBAT_RAW: F1.1, J1.1
VBAT_SENSED: F2.2, R10.1
VBUS_SENSE: C19.1, R10.2, U4.8 (Vbus)

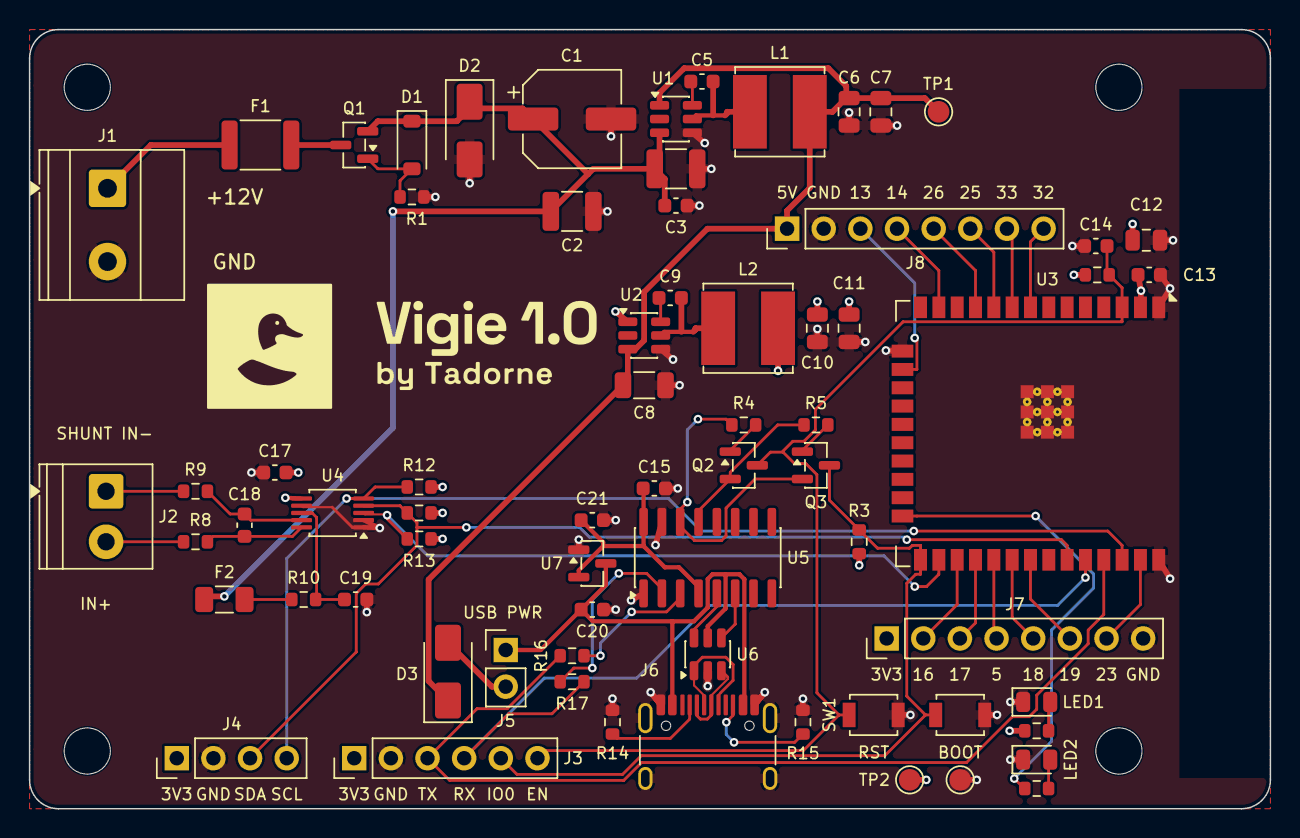
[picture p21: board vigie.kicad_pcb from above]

Board: 4 copper layers, 86.0 x 54.0 mm, 74 parts (0 on the bottom side), 54 nets.

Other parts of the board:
H1, H2, H3, H4: M3; MountingHole_3.2mm_M3
LOGO1: vigie-silk

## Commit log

2026-10-09 Site moved to site/, room for public sources
    pcb/: KiCad project of Vigie 1.0, identical to the signed vigie-1.0-kicad.zip (CERN-OHL-S v2).
    [vigie.kicad_pcb, vigie.kicad_sch]
2026-10-09 Home: kit button (to the interest page) and Join Vigie block, as on Penon
2026-10-12 Firmware du nœud énergie Vigie (GPL-3.0)
    Nœud ESP32-WROOM-32E + INA226, passerelle de banc ESP-NOW et outils BLE/journal.
2026-10-12 Journal : semelle en TPU 95 pour le shunt et la carte
    Coffret du nœud : semelle imprimée en TPU 95, chocs du shunt amortis et carte logée. Billet FR/EN et trois photos (impression, pièce finie, nœud monté).
2026-10-12 Journal : semelle en TPU, billet aligné sur la facture des autres billets
    Ouverture, sections « Ce que… » et « La suite : … », ## Où ; 230 mots en français, 209 en anglais.
2026-10-12 Journal : semelle en TPU, sections « Sur l'établi » et « Où » retirées
    Billet réduit à l'ouverture et à ce que la pièce fait : 108 mots en français, 102 en anglais.
2026-10-12 Accueil : photo du nœud monté sous la vidéo promo
